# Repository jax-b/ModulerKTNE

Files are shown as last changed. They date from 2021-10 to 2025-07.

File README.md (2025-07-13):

# --------------

# Abandoned
Dam this needs a lot of work. What was i thinking on some of the decisions. Ill rework this into several separate repos in the future

# --------------

# ModulerKTNE
A real life keep talking and nobody explodes
The goal of this project it to make a modular [Keep Talking and Nobody Explodes game](https://keeptalkinggame.com/).
I also want this project to use the original game manual!
My eventual aim is to replicate every module.

# Discord
Join the [Discord](https://discord.gg/muyrytPZhW) to talk about the project  


Lets start out with my overall plan!
Each module should be self contained, meaning that that module knows weather or not it is solved.
Each module should be able to be configured from the central controller to replicate game scenarios.
The central controller should have a easy to use web interface.
Each module should look like it does in the game.
The game should know if it is being tampered with.

Coms between the central controller and the modules will likely use I2C with a master interrupt line.

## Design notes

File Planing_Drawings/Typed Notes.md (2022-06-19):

# Typed Notes
## ModAdders
### I2C Command List
 - 0x00 Get Module Type
 - 0x01 Get Module Config (Gets current scenario id and progress)
 - 0x02 Get Module Status (Should contain if solved)
 - 0x11 Set Module Solved Status (Sets if solved)
 - 0x12 Time Sync

### Time Keeping
~~- the current countdown time should be sent out to all modules using the 0xFF address~~
### I2C Address Locations
#### Modules
##### Front
| | | |
|:-:|:-:|:-:|
| Main | F1 | F2|
| F3 | F4 | F5 |
#### Back
| | | |
|:-:|:-:|:-:|
| B2 | B1 | Main |
| B5 | B4 | B3 |
#### Sides
| | | |
|:-:|:-:|:-:|
||50||
|53| Front Face | 51|
|| 52 ||
## SideCase
 - Each Side Should have its own PCB
 - Each Side Should have some indicators of each type (excluding serial and second factor)
 - Serial and Second Factor should be on the bottom
## FrontOfDevice
### Dimensions
 - The Device
  - 25" x 18" x 5"
 - The Modules
  - 8" x 8.365" (Depth has not been determined as of writing)
  - Locking Screw should be 1/4 20
  - PoGo pins should be centered at the top of the module
  - 6 PoGo pins are required
### Master Module
 - 7 segment display for time
 - warning indicator should just be two led's with diffuses and then a mask applied to the front of the diffuse to be stars
 - Inside of the device should be a extra sd card conatining stuff like WiFi Information (Parameters that cannot be set through the web interface)
## ModSlot
### Pin Order
| | | | | | |
|:-:|:-:|:-:|:-:|:-:|:-:|
|VCC|Ground|Addr|Interrupt|Clock|Data|
 - Interupt is active low
 - Addr is a voltage divider
 - Addr's voltage must be present at time of module boot in order to get address
 - Addr Should tie to the first analog input on the chip of the Module
## New Notes
- Any information that does not change throughout the course of a defusal session should be displayed on a eInk Display
- Information that does change should use either a LCD or OLED

## Gameplay port ID's
There are 6 types of ports in the game here is the id's we use to keep track of them
```
  1 = Port
  0 = not used
  1 = DVI
  1 = Parallel
  1 = PS/2
  1 = RJ45
  1 = Serial
  1 = SteroRCA
```

## RPI_Setup
#### go-rpio 
make sure that the following is set in boot/config.txt
```dtoverlay=gpio-no-irq```
#### no sudo access 
it is recommended that groups and permissions are assigned so that the software does not have to be run as root. Here is a example config for udev assuming that the groups are already created. While SPI is not necessary its here for the future if needed 
```
SUBSYSTEM=="spidev" , GROUP="spi" , MODE="0660"
KERNEL=="i2c-0"     , GROUP="i2c" , MODE="0660"
KERNEL=="i2c-[1-9]*", GROUP="i2c" , MODE="0660"
KERNEL=="gpiomem"   , GROUP="gpio", MODE="0660"
```

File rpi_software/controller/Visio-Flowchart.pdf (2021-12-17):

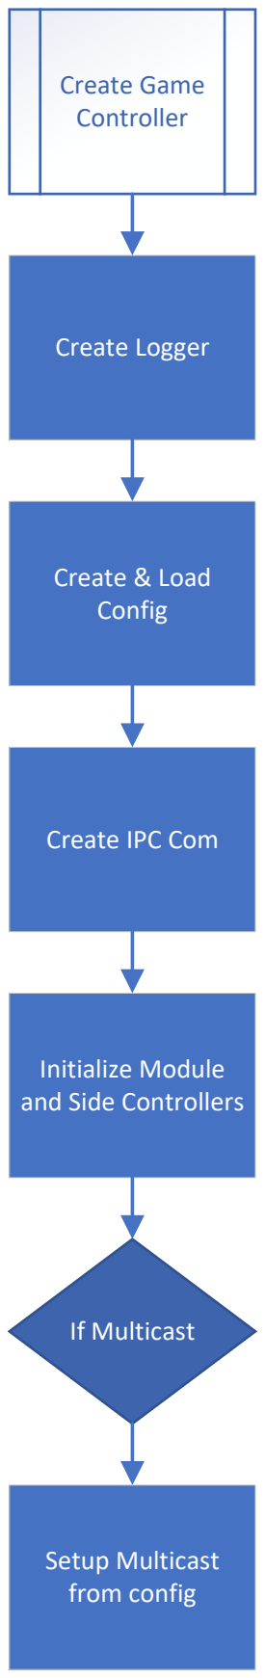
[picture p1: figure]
Create Game Controller; Create Logger; Create & Load Config; Create IPC Com; Initialize Module and Side Controllers; If Multicast; Setup Multicast from config
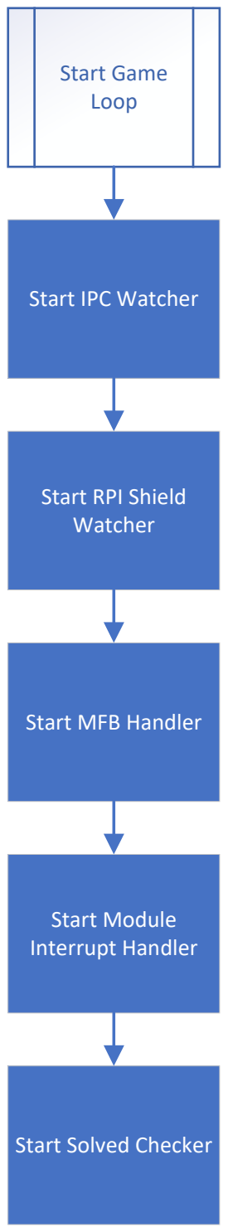
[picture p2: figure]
Start Game Loop; Start IPC Watcher; Start RPI Shield Watcher; Start Module Interrupt Handler; Start Solved Checker; Start MFB Handler

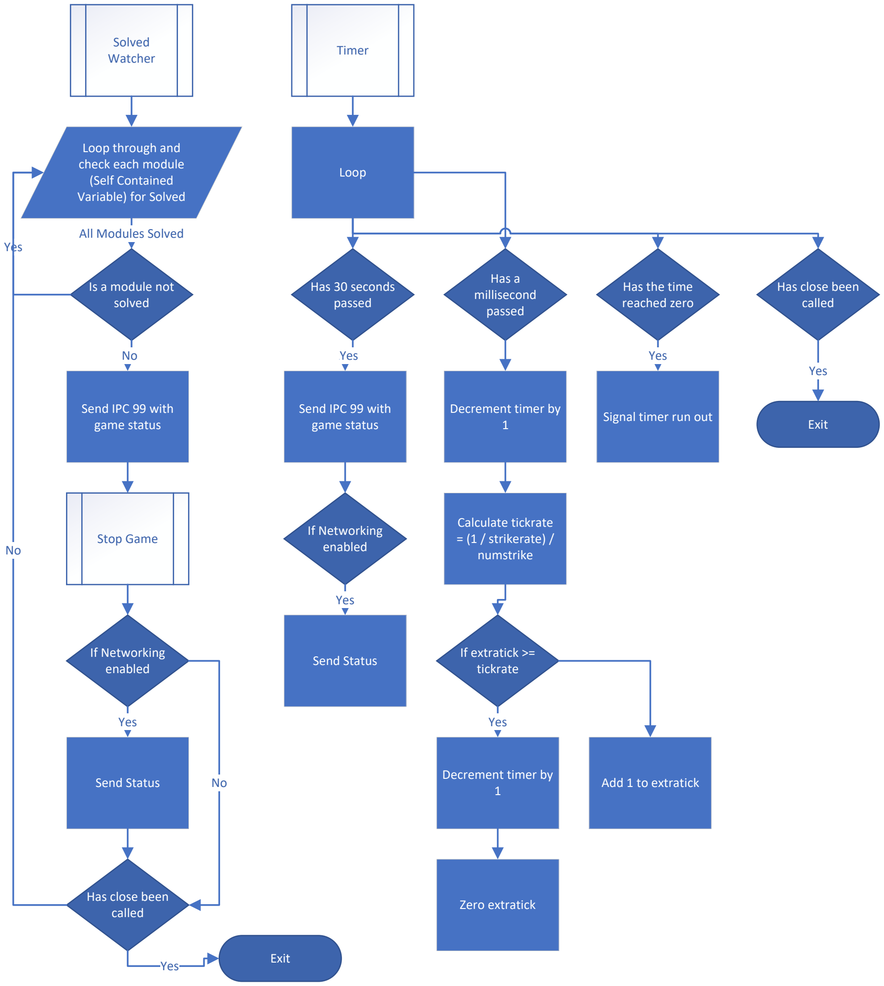
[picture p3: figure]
Solved Watcher; Is a module not solved; Yes; Loop through and check each module (Self Contained Variable) for Solved; All Modules Solved; Send IPC 99 with game status; Stop Game; If Networking enabled; Send Status; Timer; Has close been called; Has 30 seconds passed; Has a millisecond passed; Decrement timer by 1; Calculate tickrate = (1 / strikerate) / numstrike; If extratick >= tickrate; Zero extratick; Add 1 to extratick; Has the time reached zero; Signal timer run out; Exit; Exit Yes; Loop
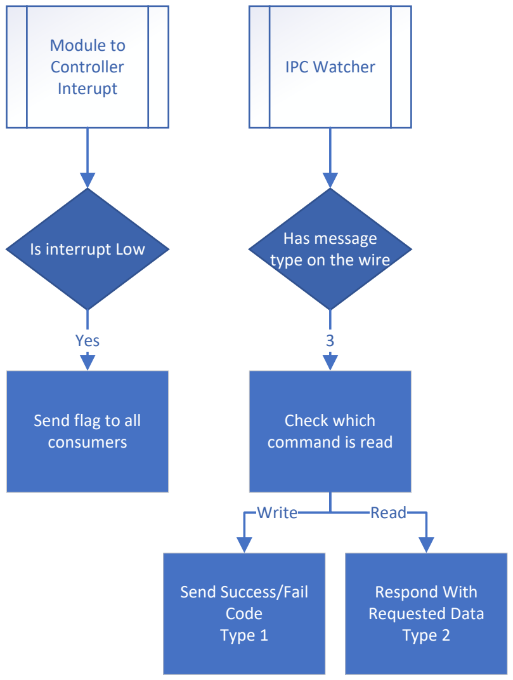
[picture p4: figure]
Module to Controller Interupt; IPC Watcher; Is interrupt Low; Send flag to all consumers; Yes; Has message type on the wire; Check which command is read; Send Success/Fail Code Type 1; Respond With Requested Data Type 2; Write; Read

Update IPC
Gamestatus

Send out current
status
Type 99

Every 10 seconds

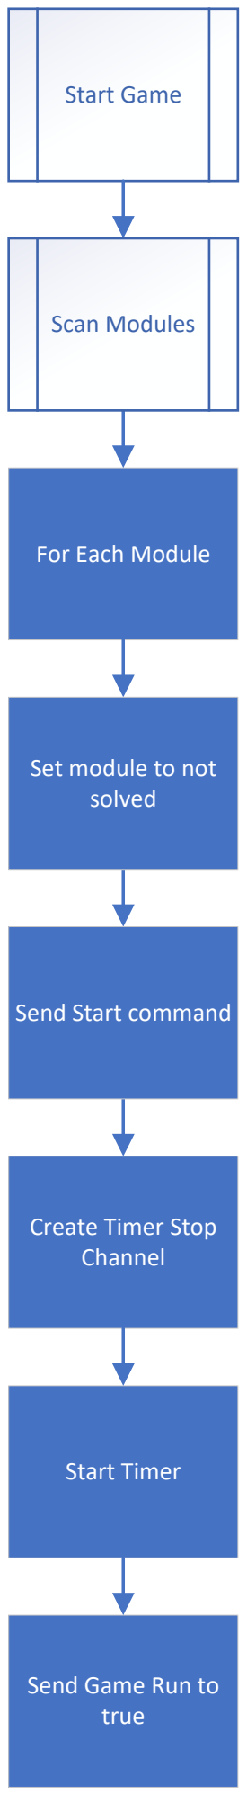
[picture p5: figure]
Start Game; For Each Module; Create Timer Stop Channel; Scan Modules; Set module to not solved; Send Start command; Start Timer; Send Game Run to true

Stop Game

Is the game
actually running

Stop Timer

Is module
present

Send Stop Game

For Each Module

Scan Modules

For Each Module

Test if module is
present

Send Full GameData
update

Yes

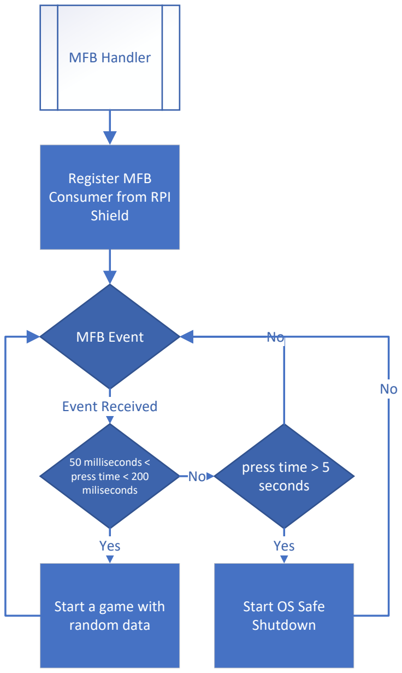
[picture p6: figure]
MFB Handler; Register MFB Consumer from RPI Shield; MFB Event; Event Received; 50 milliseconds < press time < 200 miliseconds; Start a game with random data; press time > 5 seconds; Yes; Start OS Safe Shutdown
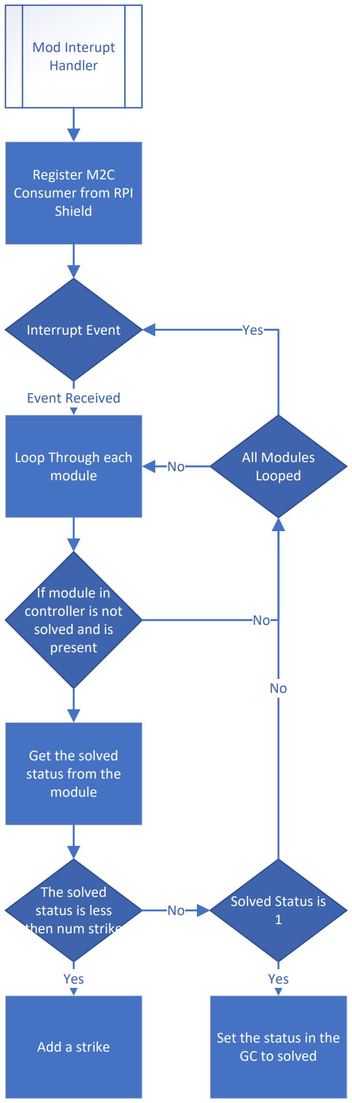
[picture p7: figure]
Mod Interupt Handler; Register M2C Consumer from RPI Shield; Interrupt Event; Loop Through each module; Event Received; If module in controller is not solved and is present; Get the solved status from the module; The solved status is less then num strike; Yes; Add a strike; Solved Status is 1 No; Set the status in the GC to solved; All Modules Looped No

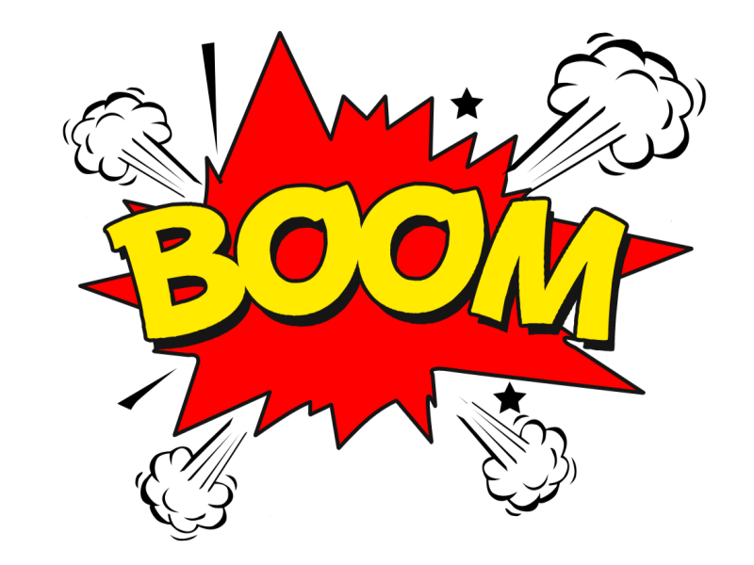
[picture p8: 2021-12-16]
rpi_software/netdisplay/cmd/webcode/images/boom.png

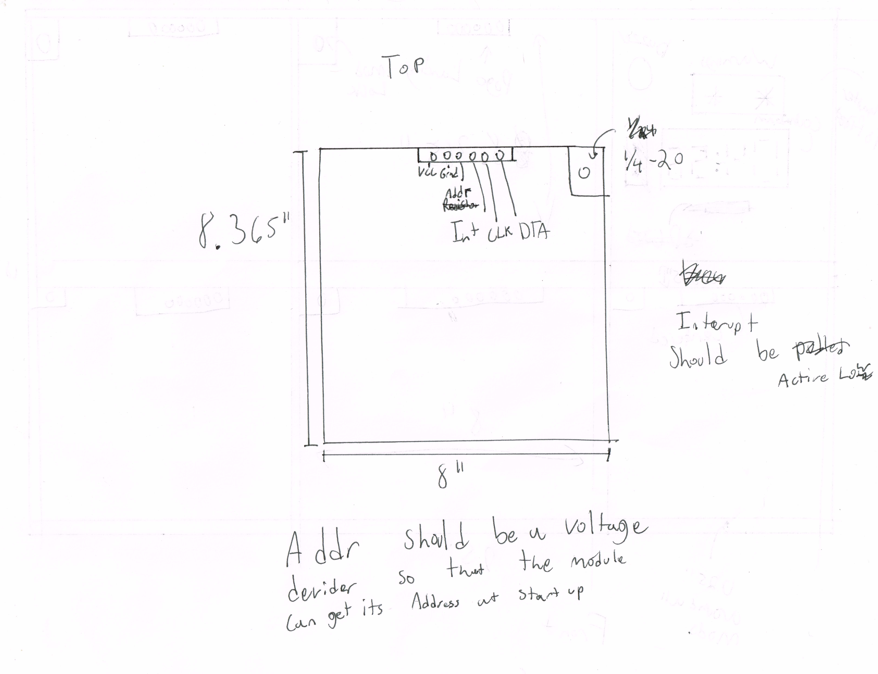
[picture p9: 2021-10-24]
Planing_Drawings/ModSlot.JPG

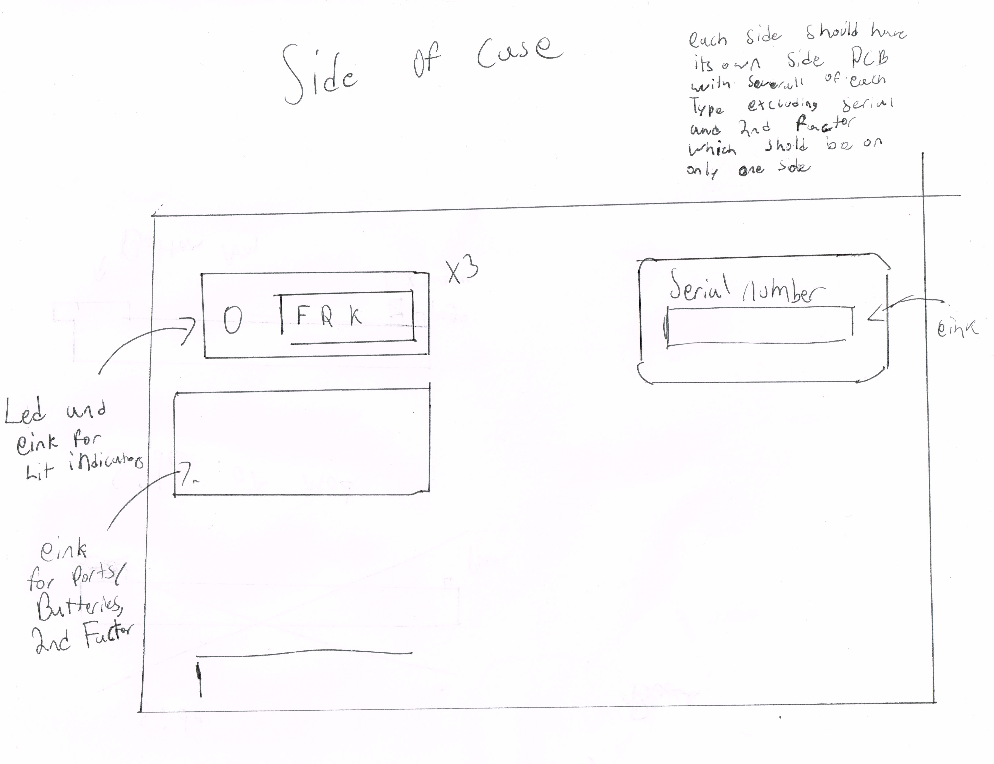
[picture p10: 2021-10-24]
Planing_Drawings/SideCase.JPG

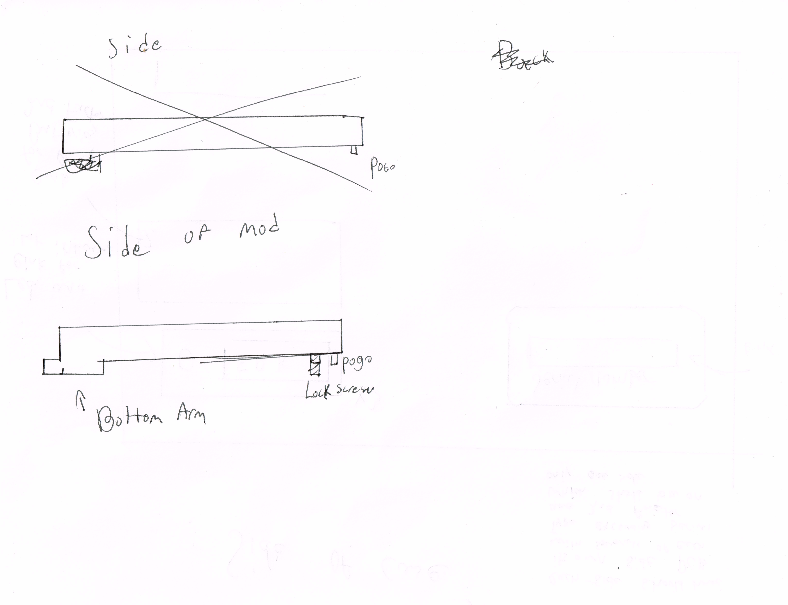
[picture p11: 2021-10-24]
Planing_Drawings/SideOfMod.JPG

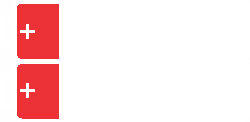
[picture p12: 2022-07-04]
SidePanel/Artwork/AA - RED.jpg

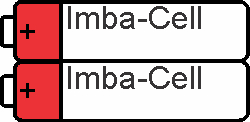
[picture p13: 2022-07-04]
SidePanel/Artwork/AA.jpg

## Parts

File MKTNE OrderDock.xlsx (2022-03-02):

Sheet: Totals
Manufacturer Part Number | Manufacturer Name | Description | Digi-Key Part Number 1 | Requested Quantity 1
ABLS-12.000MHZ-B4-T | Abracon LLC | CRYSTAL 12.0000MHZ 18PF SMD | 535-10218-1-ND | 9
A-CSL-S-020-B7-A | Assmann WSW Components | CONN PIN SPRING LOAD 5.207MM AU | AE11599-ND | 54
ADC144EUQ-13 | Diodes Incorporated | IC TRANSISTOR SOT363 | ADC144EUQ-13DICT-ND | 8
C0805Z5U500-103MNE-CT | Venkel | CAP CER 0.01UF 50V Z5U 0805 | 2679-C0805Z5U500-103MNE-CT-ND | 2
CL21A106KOQNNNE | Samsung Electro-Mechanics | CAP CER 10UF 16V X5R 0805 | 1276-1096-1-ND | 5
CL21B103KBANNNC | Samsung Electro-Mechanics | CAP CER 10000PF 50V X7R 0805 | 1276-1015-1-ND | 3
CL21B104KACNNNC | Samsung Electro-Mechanics | CAP CER 0.1UF 25V X7R 0805 | 1276-1099-1-ND | 92
CL21B105KAFNNNE | Samsung Electro-Mechanics | CAP CER 1UF 25V X7R 0805 | 1276-1066-1-ND | 15
CL21C270JCANNNC | Samsung Electro-Mechanics | CAP CER 27PF 100V C0G/NP0 0805 | 1276-2622-1-ND | 18
CL31B106KQHNFNE | Samsung Electro-Mechanics | CAP CER 10UF 6.3V X7R 1206 | 1276-3107-1-ND | 15
CMS0231KLX | CUI Devices | SPEAKER 8OHM 2W ENCLOSED 82DB | 102-1300-ND | 5
CPF0603B10KE1 | TE Connectivity Passive Product | RES SMD 10K OHM 0.1% 1/16W 0603 | A102331CT-ND | 12
CRGP0603F27R | TE Connectivity Passive Product | RES 27 OHM 1% 1/4W 0603 | A130397CT-ND | 18
CRM0805-FX-51R0ELF | Bourns Inc. | RES SMD 51 OHM 1% 1/4W 0805 | CRM0805-FX-51R0ELFCT-ND | 6
ERA-3AEB512V | Panasonic Electronic Components | RES SMD 5.1K OHM 0.1% 1/10W 0603 | P5.1KDBCT-ND | 18
ESR03EZPF1001 | Rohm Semiconductor | RES SMD 1K OHM 1% 1/4W 0603 | RHM1.00KADCT-ND | 18
JMK316BBJ107MLHT | Taiyo Yuden | CAP CER 100UF 6.3V X5R 1206 | 587-3716-1-ND | 12
MAX7221CWG+T | Analog Devices Inc./Maxim Integrated | IC DRVR 7 SEGMNT 8 DIGIT 24SOIC | MAX7221CWG+CT-ND | 2
NCP1117DTARKG | onsemi | IC REG LINEAR POS ADJ 1A DPAK | NCP1117DTARKGOSCT-ND | 9
RG1608P-562-B-T5 | Susumu | RES SMD 5.6K OHM 0.1% 1/10W 0603 | RG16P5.6KBCT-ND | 9
RK73H2ATTD1100F | KOA Speer Electronics, Inc. | RES 110 OHM 1% 1/4W 0805 | 2019-RK73H2ATTD1100FCT-ND | 12
RK73H2ATTD2700F | KOA Speer Electronics, Inc. | RES 270 OHM 1% 1/4W 0805 | 2019-RK73H2ATTD2700FCT-ND | 5
RK73H2ATTD30R0F | KOA Speer Electronics, Inc. | RES 30 OHM 1% 1/4W 0805 | 2019-RK73H2ATTD30R0FCT-ND | 14
RK73H2ATTD91R0F | KOA Speer Electronics, Inc. | RES 91 OHM 1% 1/4W 0805 | 2019-RK73H2ATTD91R0FCT-ND | 30
RNCP0805FTD150R | Stackpole Electronics Inc | RES 150 OHM 1% 1/4W 0805 | RNCP0805FTD150RCT-ND | 14
RNCP0805FTD4K99 | Stackpole Electronics Inc | RES 4.99K OHM 1% 1/4W 0805 | RNCP0805FTD4K99CT-ND | 2
S02B-XASS-1(LF)(SN) | JST Sales America Inc. | CONN HEADER R/A 2POS 2.5MM | 455-2044-ND | 2
S04B-XASK-1(LF)(SN) | JST Sales America Inc. | CONN HEADER R/A 4POS 2.5MM | 455-4090-ND | 6
S05B-XASK-1(LF)(SN) | JST Sales America Inc. | CONN HEADER R/A 5POS 2.5MM | 455-4135-ND | 30
SC0914(7) | Raspberry Pi | RP2040TR7 | 2648-SC0914(7)CT-ND | 9
SG73S2ATTD4701F | KOA Speer Electronics, Inc. | RES 4.7K OHM 1% 1/4W 0805 | 2019-SG73S2ATTD4701FCT-ND | 2
SSM2305RMZ-R2 | Analog Devices Inc. | IC AMP CLASS D MONO 2.8W 8MSOP | SSM2305RMZ-R2CT-ND | 5
W25Q128JVSIQ | Winbond Electronics | IC FLASH 128MBIT SPI/QUAD 8SOIC | W25Q128JVSIQ-ND | 9
XZDGK54W-8 | SunLED | LED GREEN CLEAR CHIP SMD | 1497-1435-1-ND | 12
XZFBB54W-8 | SunLED | LED BLUE CLEAR CHIP SMD | 1497-1437-1-ND | 12
XZMDK54W-8 | SunLED | LED RED CLEAR CHIP SMD | 1497-1431-1-ND | 28
XZMYK54W-8 | SunLED | LED YELLOW CLEAR CHIP SMD | 1497-1432-1-ND | 12

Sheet: EveryPart
Manufacturer Part Number | Manufacturer Name | Description | Digi-Key Part Number 1 | Unit Price 1 | Extended Price 1 | TotalMultipled | SRC
S05B-XASK-1(LF)(SN) | JST Sales America Inc. | CONN HEADER R/A 5POS 2.5MM | 455-4135-ND | 0.56000 | $1.12 | 22 | MKTNE_MODCON
S04B-XASK-1(LF)(SN) | JST Sales America Inc. | CONN HEADER R/A 4POS 2.5MM | 455-4090-ND | 0.53000 | $0.53 | 2 | MKTNE_POWERCON
S05B-XASK-1(LF)(SN) | JST Sales America Inc. | CONN HEADER R/A 5POS 2.5MM | 455-4135-ND | 0.56000 | $2.24 | 8 | MKTNE_RPICTRL
S04B-XASK-1(LF)(SN) | JST Sales America Inc. | CONN HEADER R/A 4POS 2.5MM | 455-4090-ND | 0.53000 | $1.06 | 4 | MKTNE_RPICTRL
ADC144EUQ-13 | Diodes Incorporated | IC TRANSISTOR SOT363 | ADC144EUQ-13DICT-ND | 0.39000 | $0.39 | 2 | MKTNE_RPICTRL
SSM2305RMZ-R2 | Analog Devices Inc. | IC AMP CLASS D MONO 2.8W 8MSOP | SSM2305RMZ-R2CT-ND | 2.53000 | $2.53 | 2 | MKTNE_RPICTRL
CMS0231KLX | CUI Devices | SPEAKER 8OHM 2W ENCLOSED 82DB | 102-1300-ND | 6.63000 | $6.63 | 2 | MKTNE_RPICTRL
CL21B104KACNNNC | Samsung Electro-Mechanics | CAP CER 0.1UF 25V X7R 0805 | 1276-1099-1-ND | 0.10000 | $0.10 | 2 | MKTNE_RPICTRL
CL21A106KOQNNNE | Samsung Electro-Mechanics | CAP CER 10UF 16V X5R 0805 | 1276-1096-1-ND | 0.11000 | $0.11 | 2 | MKTNE_RPICTRL
RK73H2ATTD2700F | KOA Speer Electronics, Inc. | RES 270 OHM 1% 1/4W 0805 | 2019-RK73H2ATTD2700FCT-ND | 0.10000 | $0.10 | 2 | MKTNE_RPICTRL
RNCP0805FTD150R | Stackpole Electronics Inc | RES 150 OHM 1% 1/4W 0805 | RNCP0805FTD150RCT-ND | 0.10000 | $0.10 | 2 | MKTNE_RPICTRL
RK73H2ATTD30R0F | KOA Speer Electronics, Inc. | RES 30 OHM 1% 1/4W 0805 | 2019-RK73H2ATTD30R0FCT-ND | 0.10000 | $0.40 | 8 | MKTNE_RPICTRL
MAX7221CWG+T | Analog Devices Inc./Maxim Integrated | IC DRVR 7 SEGMNT 8 DIGIT 24SOIC | MAX7221CWG+CT-ND | 10.77000 | $10.77 | 2 | MKTNE_RPICTRL
XZMDK54W-8 | SunLED | LED RED CLEAR CHIP SMD | 1497-1431-1-ND | 0.46000 | $3.68 | 16 | MKTNE_RPICTRL
RNCP0805FTD4K99 | Stackpole Electronics Inc | RES 4.99K OHM 1% 1/4W 0805 | RNCP0805FTD4K99CT-ND | 0.10000 | $0.10 | 2 | MKTNE_RPICTRL
SG73S2ATTD4701F | KOA Speer Electronics, Inc. | RES 4.7K OHM 1% 1/4W 0805 | 2019-SG73S2ATTD4701FCT-ND | 0.19000 | $0.19 | 2 | MKTNE_RPICTRL
S02B-XASS-1(LF)(SN) | JST Sales America Inc. | CONN HEADER R/A 2POS 2.5MM | 455-2044-ND | 0.45000 | $0.45 | 2 | MKTNE_RPICTRL
C0805Z5U500-103MNE-CT | Venkel | CAP CER 0.01UF 50V Z5U 0805 | 2679-C0805Z5U500-103MNE-CT-ND | 0.02800 | $0.14 | 2 | MKTNE_RPICTRL
XZFBB54W-8 | SunLED | LED BLUE CLEAR CHIP SMD | 1497-1437-1-ND | 0.57000 | $2.28 | 12 | OTS_Simon
XZMYK54W-8 | SunLED | LED YELLOW CLEAR CHIP SMD | 1497-1432-1-ND | 0.46000 | $1.84 | 12 | OTS_Simon
XZDGK54W-8 | SunLED | LED GREEN CLEAR CHIP SMD | 1497-1435-1-ND | 0.67000 | $2.68 | 12 | OTS_Simon
XZMDK54W-8 | SunLED | LED RED CLEAR CHIP SMD | 1497-1431-1-ND | 0.46000 | $1.84 | 12 | OTS_Simon
W25Q128JVSIQ | Winbond Electronics | IC FLASH 128MBIT SPI/QUAD 8SOIC | W25Q128JVSIQ-ND | 1.88000 | $1.88 | 3 | OTS_Simon
NCP1117DTARKG | onsemi | IC REG LINEAR POS ADJ 1A DPAK | NCP1117DTARKGOSCT-ND | 0.63000 | $0.63 | 3 | OTS_Simon
SC0914(7) | Raspberry Pi | RP2040TR7 | 2648-SC0914(7)CT-ND | 1.00000 | $1.00 | 3 | OTS_Simon
ABLS-12.000MHZ-B4-T | Abracon LLC | CRYSTAL 12.0000MHZ 18PF SMD | 535-10218-1-ND | 0.32000 | $0.32 | 3 | OTS_Simon
SSM2305RMZ-R2 | Analog Devices Inc. | IC AMP CLASS D MONO 2.8W 8MSOP | SSM2305RMZ-R2CT-ND | 2.53000 | $2.53 | 3 | OTS_Simon
ADC144EUQ-13 | Diodes Incorporated | IC TRANSISTOR SOT363 | ADC144EUQ-13DICT-ND | 0.39000 | $0.78 | 6 | OTS_Simon
CMS0231KLX | CUI Devices | SPEAKER 8OHM 2W ENCLOSED 82DB | 102-1300-ND | 6.63000 | $6.63 | 3 | OTS_Simon
A-CSL-S-020-B7-A | Assmann WSW Components | CONN PIN SPRING LOAD 5.207MM AU | AE11599-ND | 0.78000 | $4.68 | 18 | OTS_Simon
CL31B106KQHNFNE | Samsung Electro-Mechanics | CAP CER 10UF 6.3V X7R 1206 | 1276-3107-1-ND | 0.18000 | $0.18 | 3 | OTS_Simon
CRGP0603F27R | TE Connectivity Passive Product | RES 27 OHM 1% 1/4W 0603 | A130397CT-ND | 0.18000 | $0.36 | 6 | OTS_Simon
RNCP0805FTD150R | Stackpole Electronics Inc | RES 150 OHM 1% 1/4W 0805 | RNCP0805FTD150RCT-ND | 0.10000 | $0.20 | 6 | OTS_Simon
RK73H2ATTD91R0F | KOA Speer Electronics, Inc. | RES 91 OHM 1% 1/4W 0805 | 2019-RK73H2ATTD91R0FCT-ND | 0.10000 | $0.60 | 18 | OTS_Simon
CL21C270JCANNNC | Samsung Electro-Mechanics | CAP CER 27PF 100V C0G/NP0 0805 | 1276-2622-1-ND | 0.10000 | $0.20 | 6 | OTS_Simon
CL21A106KOQNNNE | Samsung Electro-Mechanics | CAP CER 10UF 16V X5R 0805 | 1276-1096-1-ND | 0.11000 | $0.11 | 3 | OTS_Simon
CL21B103KBANNNC | Samsung Electro-Mechanics | CAP CER 10000PF 50V X7R 0805 | 1276-1015-1-ND | 0.10000 | $0.10 | 3 | OTS_Simon
CL21B104KACNNNC | Samsung Electro-Mechanics | CAP CER 0.1UF 25V X7R 0805 | 1276-1099-1-ND | 0.04000 | $0.40 | 30 | OTS_Simon
RG1608P-562-B-T5 | Susumu | RES SMD 5.6K OHM 0.1% 1/10W 0603 | RG16P5.6KBCT-ND | 0.50000 | $0.50 | 3 | OTS_Simon
ERA-3AEB512V | Panasonic Electronic Components | RES SMD 5.1K OHM 0.1% 1/10W 0603 | P5.1KDBCT-ND | 0.35000 | $0.70 | 6 | OTS_Simon
CPF0603B10KE1 | TE Connectivity Passive Product | RES SMD 10K OHM 0.1% 1/16W 0603 | A102331CT-ND | 0.67000 | $0.67 | 3 | OTS_Simon
ESR03EZPF1001 | Rohm Semiconductor | RES SMD 1K OHM 1% 1/4W 0603 | RHM1.00KADCT-ND | 0.15000 | $0.30 | 6 | OTS_Simon
CRM0805-FX-51R0ELF | Bourns Inc. | RES SMD 51 OHM 1% 1/4W 0805 | CRM0805-FX-51R0ELFCT-ND | 0.10000 | $0.20 | 6 | OTS_Simon
RK73H2ATTD30R0F | KOA Speer Electronics, Inc. | RES 30 OHM 1% 1/4W 0805 | 2019-RK73H2ATTD30R0FCT-ND | 0.10000 | $0.20 | 6 | OTS_Simon
RK73H2ATTD1100F | KOA Speer Electronics, Inc. | RES 110 OHM 1% 1/4W 0805 | 2019-RK73H2ATTD1100FCT-ND | 0.10000 | $0.40 | 12 | OTS_Simon
RK73H2ATTD2700F | KOA Speer Electronics, Inc. | RES 270 OHM 1% 1/4W 0805 | 2019-RK73H2ATTD2700FCT-ND | 0.10000 | $0.10 | 3 | OTS_Simon
CL21B105KAFNNNE | Samsung Electro-Mechanics | CAP CER 1UF 25V X7R 0805 | 1276-1066-1-ND | 0.10000 | $0.20 | 6 | OTS_Simon
W25Q128JVSIQ | Winbond Electronics | IC FLASH 128MBIT SPI/QUAD 8SOIC | W25Q128JVSIQ-ND | 1.88000 | $1.88 | 3 | OTS_Button
NCP1117DTARKG | onsemi | IC REG LINEAR POS ADJ 1A DPAK | NCP1117DTARKGOSCT-ND | 0.63000 | $0.63 | 3 | OTS_Button
SC0914(7) | Raspberry Pi | RP2040TR7 | 2648-SC0914(7)CT-ND | 1.00000 | $1.00 | 3 | OTS_Button
ABLS-12.000MHZ-B4-T | Abracon LLC | CRYSTAL 12.0000MHZ 18PF SMD | 535-10218-1-ND | 0.32000 | $0.32 | 3 | OTS_Button
A-CSL-S-020-B7-A | Assmann WSW Components | CONN PIN SPRING LOAD 5.207MM AU | AE11599-ND | 0.78000 | $4.68 | 18 | OTS_Button
RNCP0805FTD150R | Stackpole Electronics Inc | RES 150 OHM 1% 1/4W 0805 | RNCP0805FTD150RCT-ND | 0.10000 | $0.10 | 3 | OTS_Button
RK73H2ATTD91R0F | KOA Speer Electronics, Inc. | RES 91 OHM 1% 1/4W 0805 | 2019-RK73H2ATTD91R0FCT-ND | 0.10000 | $0.20 | 6 | OTS_Button
CRGP0603F27R | TE Connectivity Passive Product | RES 27 OHM 1% 1/4W 0603 | A130397CT-ND | 0.18000 | $0.36 | 6 | OTS_Button
ERA-3AEB512V | Panasonic Electronic Components | RES SMD 5.1K OHM 0.1% 1/10W 0603 | P5.1KDBCT-ND | 0.35000 | $0.70 | 6 | OTS_Button
CPF0603B10KE1 | TE Connectivity Passive Product | RES SMD 10K OHM 0.1% 1/16W 0603 | A102331CT-ND | 0.67000 | $1.34 | 6 | OTS_Button
CL21B104KACNNNC | Samsung Electro-Mechanics | CAP CER 0.1UF 25V X7R 0805 | 1276-1099-1-ND | 0.04000 | $0.40 | 30 | OTS_Button
CL21B105KAFNNNE | Samsung Electro-Mechanics | CAP CER 1UF 25V X7R 0805 | 1276-1066-1-ND | 0.10000 | $0.10 | 3 | OTS_Button
RG1608P-562-B-T5 | Susumu | RES SMD 5.6K OHM 0.1% 1/10W 0603 | RG16P5.6KBCT-ND | 0.50000 | $0.50 | 3 | OTS_Button
ESR03EZPF1001 | Rohm Semiconductor | RES SMD 1K OHM 1% 1/4W 0603 | RHM1.00KADCT-ND | 0.15000 | $0.30 | 6 | OTS_Button
CL21C270JCANNNC | Samsung Electro-Mechanics | CAP CER 27PF 100V C0G/NP0 0805 | 1276-2622-1-ND | 0.10000 | $0.20 | 6 | OTS_Button
CL31B106KQHNFNE | Samsung Electro-Mechanics | CAP CER 10UF 6.3V X7R 1206 | 1276-3107-1-ND | 0.18000 | $0.36 | 6 | OTS_Button
JMK316BBJ107MLHT | Taiyo Yuden | CAP CER 100UF 6.3V X5R 1206 | 587-3716-1-ND | 0.72000 | $1.44 | 6 | OTS_Button
JMK316BBJ107MLHT | Taiyo Yuden | CAP CER 100UF 6.3V X5R 1206 | 587-3716-1-ND | 0.72000 | $1.44 | 6 | OTS_Wires
CL31B106KQHNFNE | Samsung Electro-Mechanics | CAP CER 10UF 6.3V X7R 1206 | 1276-3107-1-ND | 0.18000 | $0.36 | 6 | OTS_Wires
CL21B104KACNNNC | Samsung Electro-Mechanics | CAP CER 0.1UF 25V X7R 0805 | 1276-1099-1-ND | 0.04000 | $0.40 | 30 | OTS_Wires
CL21B105KAFNNNE | Samsung Electro-Mechanics | CAP CER 1UF 25V X7R 0805 | 1276-1066-1-ND | 0.10000 | $0.20 | 6 | OTS_Wires
CL21C270JCANNNC | Samsung Electro-Mechanics | CAP CER 27PF 100V C0G/NP0 0805 | 1276-2622-1-ND | 0.10000 | $0.20 | 6 | OTS_Wires
A-CSL-S-020-B7-A | Assmann WSW Components | CONN PIN SPRING LOAD 5.207MM AU | AE11599-ND | 0.78000 | $4.68 | 18 | OTS_Wires
RG1608P-562-B-T5 | Susumu | RES SMD 5.6K OHM 0.1% 1/10W 0603 | RG16P5.6KBCT-ND | 0.50000 | $0.50 | 3 | OTS_Wires
CPF0603B10KE1 | TE Connectivity Passive Product | RES SMD 10K OHM 0.1% 1/16W 0603 | A102331CT-ND | 0.67000 | $0.67 | 3 | OTS_Wires
ERA-3AEB512V | Panasonic Electronic Components | RES SMD 5.1K OHM 0.1% 1/10W 0603 | P5.1KDBCT-ND | 0.35000 | $0.70 | 6 | OTS_Wires
ESR03EZPF1001 | Rohm Semiconductor | RES SMD 1K OHM 1% 1/4W 0603 | RHM1.00KADCT-ND | 0.15000 | $0.30 | 6 | OTS_Wires
CRGP0603F27R | TE Connectivity Passive Product | RES 27 OHM 1% 1/4W 0603 | A130397CT-ND | 0.18000 | $0.36 | 6 | OTS_Wires
RK73H2ATTD91R0F | KOA Speer Electronics, Inc. | RES 91 OHM 1% 1/4W 0805 | 2019-RK73H2ATTD91R0FCT-ND | 0.10000 | $0.20 | 6 | OTS_Wires
RNCP0805FTD150R | Stackpole Electronics Inc | RES 150 OHM 1% 1/4W 0805 | RNCP0805FTD150RCT-ND | 0.10000 | $0.10 | 3 | OTS_Wires
NCP1117DTARKG | onsemi | IC REG LINEAR POS ADJ 1A DPAK | NCP1117DTARKGOSCT-ND | 0.63000 | $0.63 | 3 | OTS_Wires
W25Q128JVSIQ | Winbond Electronics | IC FLASH 128MBIT SPI/QUAD 8SOIC | W25Q128JVSIQ-ND | 1.88000 | $1.88 | 3 | OTS_Wires
SC0914(7) | Raspberry Pi | RP2040TR7 | 2648-SC0914(7)CT-ND | 1.00000 | $1.00 | 3 | OTS_Wires
ABLS-12.000MHZ-B4-T | Abracon LLC | CRYSTAL 12.0000MHZ 18PF SMD | 535-10218-1-ND | 0.32000 | $0.32 | 3 | OTS_Wires

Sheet: MKTNE_MODCON
Manufacturer Part Number | Manufacturer Name | Description | Requested Quantity 1 | Digi-Key Part Number 1 | Unit Price 1 | Extended Price 1 | TotalQTY | Multiplier
S05B-XASK-1(LF)(SN) | JST Sales America Inc. | CONN HEADER R/A 5POS 2.5MM | 2 | 455-4135-ND | 0.56000 | $1.12 | 22 | 11

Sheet: MKTNE_POWERCON
Manufacturer Part Number | Manufacturer Name | Description | Requested Quantity 1 | Digi-Key Part Number 1 | Unit Price 1 | Extended Price 1 | TotalQTY | Multiplier
S04B-XASK-1(LF)(SN) | JST Sales America Inc. | CONN HEADER R/A 4POS 2.5MM | 1 | 455-4090-ND | 0.53000 | $0.53 | 2 | 2

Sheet: MKTNE_RPICTRL
Manufacturer Part Number | Manufacturer Name | Description | Requested Quantity 1 | Digi-Key Part Number 1 | Unit Price 1 | Extended Price 1 | TotalQTY | Multiplier
S05B-XASK-1(LF)(SN) | JST Sales America Inc. | CONN HEADER R/A 5POS 2.5MM | 4 | 455-4135-ND | 0.56000 | $2.24 | 8 | 2
S04B-XASK-1(LF)(SN) | JST Sales America Inc. | CONN HEADER R/A 4POS 2.5MM | 2 | 455-4090-ND | 0.53000 | $1.06 | 4
ADC144EUQ-13 | Diodes Incorporated | IC TRANSISTOR SOT363 | 1 | ADC144EUQ-13DICT-ND | 0.39000 | $0.39 | 2
SSM2305RMZ-R2 | Analog Devices Inc. | IC AMP CLASS D MONO 2.8W 8MSOP | 1 | SSM2305RMZ-R2CT-ND | 2.53000 | $2.53 | 2
CMS0231KLX | CUI Devices | SPEAKER 8OHM 2W ENCLOSED 82DB | 1 | 102-1300-ND | 6.63000 | $6.63 | 2
CL21B104KACNNNC | Samsung Electro-Mechanics | CAP CER 0.1UF 25V X7R 0805 | 1 | 1276-1099-1-ND | 0.10000 | $0.10 | 2
CL21A106KOQNNNE | Samsung Electro-Mechanics | CAP CER 10UF 16V X5R 0805 | 1 | 1276-1096-1-ND | 0.11000 | $0.11 | 2
RK73H2ATTD2700F | KOA Speer Electronics, Inc. | RES 270 OHM 1% 1/4W 0805 | 1 | 2019-RK73H2ATTD2700FCT-ND | 0.10000 | $0.10 | 2
RNCP0805FTD150R | Stackpole Electronics Inc | RES 150 OHM 1% 1/4W 0805 | 1 | RNCP0805FTD150RCT-ND | 0.10000 | $0.10 | 2
RK73H2ATTD30R0F | KOA Speer Electronics, Inc. | RES 30 OHM 1% 1/4W 0805 | 4 | 2019-RK73H2ATTD30R0FCT-ND | 0.10000 | $0.40 | 8
MAX7221CWG+T | Analog Devices Inc./Maxim Integrated | IC DRVR 7 SEGMNT 8 DIGIT 24SOIC | 1 | MAX7221CWG+CT-ND | 10.77000 | $10.77 | 2
XZMDK54W-8 | SunLED | LED RED CLEAR CHIP SMD | 8 | 1497-1431-1-ND | 0.46000 | $3.68 | 16
RNCP0805FTD4K99 | Stackpole Electronics Inc | RES 4.99K OHM 1% 1/4W 0805 | 1 | RNCP0805FTD4K99CT-ND | 0.10000 | $0.10 | 2
SG73S2ATTD4701F | KOA Speer Electronics, Inc. | RES 4.7K OHM 1% 1/4W 0805 | 1 | 2019-SG73S2ATTD4701FCT-ND | 0.19000 | $0.19 | 2
S02B-XASS-1(LF)(SN) | JST Sales America Inc. | CONN HEADER R/A 2POS 2.5MM | 1 | 455-2044-ND | 0.45000 | $0.45 | 2
C0805Z5U500-103MNE-CT | Venkel | CAP CER 0.01UF 50V Z5U 0805 | 1 | 2679-C0805Z5U500-103MNE-CT-ND | 0.02800 | $0.14 | 2

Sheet: OTS_Simon
Manufacturer Part Number | Manufacturer Name | Description | Requested Quantity 1 | Digi-Key Part Number 1 | Unit Price 1 | Extended Price 1 | TotalQTY | Multiplier
XZFBB54W-8 | SunLED | LED BLUE CLEAR CHIP SMD | 4 | 1497-1437-1-ND | 0.57000 | $2.28 | 12 | 3
XZMYK54W-8 | SunLED | LED YELLOW CLEAR CHIP SMD | 4 | 1497-1432-1-ND | 0.46000 | $1.84 | 12
XZDGK54W-8 | SunLED | LED GREEN CLEAR CHIP SMD | 4 | 1497-1435-1-ND | 0.67000 | $2.68 | 12
XZMDK54W-8 | SunLED | LED RED CLEAR CHIP SMD | 4 | 1497-1431-1-ND | 0.46000 | $1.84 | 12
W25Q128JVSIQ | Winbond Electronics | IC FLASH 128MBIT SPI/QUAD 8SOIC | 1 | W25Q128JVSIQ-ND | 1.88000 | $1.88 | 3
NCP1117DTARKG | onsemi | IC REG LINEAR POS ADJ 1A DPAK | 1 | NCP1117DTARKGOSCT-ND | 0.63000 | $0.63 | 3
SC0914(7) | Raspberry Pi | RP2040TR7 | 1 | 2648-SC0914(7)CT-ND | 1.00000 | $1.00 | 3
ABLS-12.000MHZ-B4-T | Abracon LLC | CRYSTAL 12.0000MHZ 18PF SMD | 1 | 535-10218-1-ND | 0.32000 | $0.32 | 3
SSM2305RMZ-R2 | Analog Devices Inc. | IC AMP CLASS D MONO 2.8W 8MSOP | 1 | SSM2305RMZ-R2CT-ND | 2.53000 | $2.53 | 3
ADC144EUQ-13 | Diodes Incorporated | IC TRANSISTOR SOT363 | 2 | ADC144EUQ-13DICT-ND | 0.39000 | $0.78 | 6
CMS0231KLX | CUI Devices | SPEAKER 8OHM 2W ENCLOSED 82DB | 1 | 102-1300-ND | 6.63000 | $6.63 | 3
A-CSL-S-020-B7-A | Assmann WSW Components | CONN PIN SPRING LOAD 5.207MM AU | 6 | AE11599-ND | 0.78000 | $4.68 | 18
CL31B106KQHNFNE | Samsung Electro-Mechanics | CAP CER 10UF 6.3V X7R 1206 | 1 | 1276-3107-1-ND | 0.18000 | $0.18 | 3
CRGP0603F27R | TE Connectivity Passive Product | RES 27 OHM 1% 1/4W 0603 | 2 | A130397CT-ND | 0.18000 | $0.36 | 6
RNCP0805FTD150R | Stackpole Electronics Inc | RES 150 OHM 1% 1/4W 0805 | 2 | RNCP0805FTD150RCT-ND | 0.10000 | $0.20 | 6
RK73H2ATTD91R0F | KOA Speer Electronics, Inc. | RES 91 OHM 1% 1/4W 0805 | 6 | 2019-RK73H2ATTD91R0FCT-ND | 0.10000 | $0.60 | 18
CL21C270JCANNNC | Samsung Electro-Mechanics | CAP CER 27PF 100V C0G/NP0 0805 | 2 | 1276-2622-1-ND | 0.10000 | $0.20 | 6
CL21A106KOQNNNE | Samsung Electro-Mechanics | CAP CER 10UF 16V X5R 0805 | 1 | 1276-1096-1-ND | 0.11000 | $0.11 | 3
CL21B103KBANNNC | Samsung Electro-Mechanics | CAP CER 10000PF 50V X7R 0805 | 1 | 1276-1015-1-ND | 0.10000 | $0.10 | 3
CL21B104KACNNNC | Samsung Electro-Mechanics | CAP CER 0.1UF 25V X7R 0805 | 10 | 1276-1099-1-ND | 0.04000 | $0.40 | 30
RG1608P-562-B-T5 | Susumu | RES SMD 5.6K OHM 0.1% 1/10W 0603 | 1 | RG16P5.6KBCT-ND | 0.50000 | $0.50 | 3
ERA-3AEB512V | Panasonic Electronic Components | RES SMD 5.1K OHM 0.1% 1/10W 0603 | 2 | P5.1KDBCT-ND | 0.35000 | $0.70 | 6
CPF0603B10KE1 | TE Connectivity Passive Product | RES SMD 10K OHM 0.1% 1/16W 0603 | 1 | A102331CT-ND | 0.67000 | $0.67 | 3
ESR03EZPF1001 | Rohm Semiconductor | RES SMD 1K OHM 1% 1/4W 0603 | 2 | RHM1.00KADCT-ND | 0.15000 | $0.30 | 6
CRM0805-FX-51R0ELF | Bourns Inc. | RES SMD 51 OHM 1% 1/4W 0805 | 2 | CRM0805-FX-51R0ELFCT-ND | 0.10000 | $0.20 | 6
RK73H2ATTD30R0F | KOA Speer Electronics, Inc. | RES 30 OHM 1% 1/4W 0805 | 2 | 2019-RK73H2ATTD30R0FCT-ND | 0.10000 | $0.20 | 6
RK73H2ATTD1100F | KOA Speer Electronics, Inc. | RES 110 OHM 1% 1/4W 0805 | 4 | 2019-RK73H2ATTD1100FCT-ND | 0.10000 | $0.40 | 12
RK73H2ATTD2700F | KOA Speer Electronics, Inc. | RES 270 OHM 1% 1/4W 0805 | 1 | 2019-RK73H2ATTD2700FCT-ND | 0.10000 | $0.10 | 3
CL21B105KAFNNNE | Samsung Electro-Mechanics | CAP CER 1UF 25V X7R 0805 | 2 | 1276-1066-1-ND | 0.10000 | $0.20 | 6

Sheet: OTS_Button
Manufacturer Part Number | Manufacturer Name | Description | Requested Quantity 1 | Digi-Key Part Number 1 | Unit Price 1 | Extended Price 1 | TotalQTY | Multiplier
W25Q128JVSIQ | Winbond Electronics | IC FLASH 128MBIT SPI/QUAD 8SOIC | 1 | W25Q128JVSIQ-ND | 1.88000 | $1.88 | 3 | 3
NCP1117DTARKG | onsemi | IC REG LINEAR POS ADJ 1A DPAK | 1 | NCP1117DTARKGOSCT-ND | 0.63000 | $0.63 | 3
SC0914(7) | Raspberry Pi | RP2040TR7 | 1 | 2648-SC0914(7)CT-ND | 1.00000 | $1.00 | 3
ABLS-12.000MHZ-B4-T | Abracon LLC | CRYSTAL 12.0000MHZ 18PF SMD | 1 | 535-10218-1-ND | 0.32000 | $0.32 | 3
A-CSL-S-020-B7-A | Assmann WSW Components | CONN PIN SPRING LOAD 5.207MM AU | 6 | AE11599-ND | 0.78000 | $4.68 | 18
RNCP0805FTD150R | Stackpole Electronics Inc | RES 150 OHM 1% 1/4W 0805 | 1 | RNCP0805FTD150RCT-ND | 0.10000 | $0.10 | 3
RK73H2ATTD91R0F | KOA Speer Electronics, Inc. | RES 91 OHM 1% 1/4W 0805 | 2 | 2019-RK73H2ATTD91R0FCT-ND | 0.10000 | $0.20 | 6
CRGP0603F27R | TE Connectivity Passive Product | RES 27 OHM 1% 1/4W 0603 | 2 | A130397CT-ND | 0.18000 | $0.36 | 6
ERA-3AEB512V | Panasonic Electronic Components | RES SMD 5.1K OHM 0.1% 1/10W 0603 | 2 | P5.1KDBCT-ND | 0.35000 | $0.70 | 6
CPF0603B10KE1 | TE Connectivity Passive Product | RES SMD 10K OHM 0.1% 1/16W 0603 | 2 | A102331CT-ND | 0.67000 | $1.34 | 6
CL21B104KACNNNC | Samsung Electro-Mechanics | CAP CER 0.1UF 25V X7R 0805 | 10 | 1276-1099-1-ND | 0.04000 | $0.40 | 30
CL21B105KAFNNNE | Samsung Electro-Mechanics | CAP CER 1UF 25V X7R 0805 | 1 | 1276-1066-1-ND | 0.10000 | $0.10 | 3
RG1608P-562-B-T5 | Susumu | RES SMD 5.6K OHM 0.1% 1/10W 0603 | 1 | RG16P5.6KBCT-ND | 0.50000 | $0.50 | 3
ESR03EZPF1001 | Rohm Semiconductor | RES SMD 1K OHM 1% 1/4W 0603 | 2 | RHM1.00KADCT-ND | 0.15000 | $0.30 | 6
CL21C270JCANNNC | Samsung Electro-Mechanics | CAP CER 27PF 100V C0G/NP0 0805 | 2 | 1276-2622-1-ND | 0.10000 | $0.20 | 6
CL31B106KQHNFNE | Samsung Electro-Mechanics | CAP CER 10UF 6.3V X7R 1206 | 2 | 1276-3107-1-ND | 0.18000 | $0.36 | 6
JMK316BBJ107MLHT | Taiyo Yuden | CAP CER 100UF 6.3V X5R 1206 | 2 | 587-3716-1-ND | 0.72000 | $1.44 | 6

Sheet: OTS_Wires
Manufacturer Part Number | Manufacturer Name | Description | Requested Quantity 1 | Digi-Key Part Number 1 | Unit Price 1 | Extended Price 1 | TotalQTY | Multiplier
JMK316BBJ107MLHT | Taiyo Yuden | CAP CER 100UF 6.3V X5R 1206 | 2 | 587-3716-1-ND | 0.72000 | $1.44 | 6 | 3
CL31B106KQHNFNE | Samsung Electro-Mechanics | CAP CER 10UF 6.3V X7R 1206 | 2 | 1276-3107-1-ND | 0.18000 | $0.36 | 6
CL21B104KACNNNC | Samsung Electro-Mechanics | CAP CER 0.1UF 25V X7R 0805 | 10 | 1276-1099-1-ND | 0.04000 | $0.40 | 30
CL21B105KAFNNNE | Samsung Electro-Mechanics | CAP CER 1UF 25V X7R 0805 | 2 | 1276-1066-1-ND | 0.10000 | $0.20 | 6
CL21C270JCANNNC | Samsung Electro-Mechanics | CAP CER 27PF 100V C0G/NP0 0805 | 2 | 1276-2622-1-ND | 0.10000 | $0.20 | 6
A-CSL-S-020-B7-A | Assmann WSW Components | CONN PIN SPRING LOAD 5.207MM AU | 6 | AE11599-ND | 0.78000 | $4.68 | 18
RG1608P-562-B-T5 | Susumu | RES SMD 5.6K OHM 0.1% 1/10W 0603 | 1 | RG16P5.6KBCT-ND | 0.50000 | $0.50 | 3
CPF0603B10KE1 | TE Connectivity Passive Product | RES SMD 10K OHM 0.1% 1/16W 0603 | 1 | A102331CT-ND | 0.67000 | $0.67 | 3
ERA-3AEB512V | Panasonic Electronic Components | RES SMD 5.1K OHM 0.1% 1/10W 0603 | 2 | P5.1KDBCT-ND | 0.35000 | $0.70 | 6
ESR03EZPF1001 | Rohm Semiconductor | RES SMD 1K OHM 1% 1/4W 0603 | 2 | RHM1.00KADCT-ND | 0.15000 | $0.30 | 6
CRGP0603F27R | TE Connectivity Passive Product | RES 27 OHM 1% 1/4W 0603 | 2 | A130397CT-ND | 0.18000 | $0.36 | 6
RK73H2ATTD91R0F | KOA Speer Electronics, Inc. | RES 91 OHM 1% 1/4W 0805 | 2 | 2019-RK73H2ATTD91R0FCT-ND | 0.10000 | $0.20 | 6
RNCP0805FTD150R | Stackpole Electronics Inc | RES 150 OHM 1% 1/4W 0805 | 1 | RNCP0805FTD150RCT-ND | 0.10000 | $0.10 | 3
NCP1117DTARKG | onsemi | IC REG LINEAR POS ADJ 1A DPAK | 1 | NCP1117DTARKGOSCT-ND | 0.63000 | $0.63 | 3
W25Q128JVSIQ | Winbond Electronics | IC FLASH 128MBIT SPI/QUAD 8SOIC | 1 | W25Q128JVSIQ-ND | 1.88000 | $1.88 | 3
SC0914(7) | Raspberry Pi | RP2040TR7 | 1 | 2648-SC0914(7)CT-ND | 1.00000 | $1.00 | 3
ABLS-12.000MHZ-B4-T | Abracon LLC | CRYSTAL 12.0000MHZ 18PF SMD | 1 | 535-10218-1-ND | 0.32000 | $0.32 | 3

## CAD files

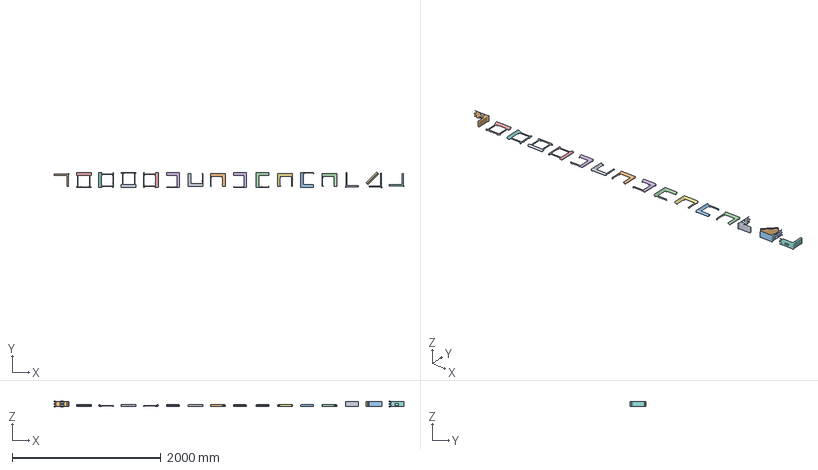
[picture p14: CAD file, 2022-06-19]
Frame v26.3mf
4701.1 x 210.0 x 71.1 mm
Bottom Back Mid
Bottom Back Right
Bottom Back left
Bottom Front Left
Bottom Front Mid
Bottom Front Right
Mid Back Mid
Mid Back Left
Mid Front Right x 2
Mid Front Mid
Top Back Left
Top Back Mid
Top Back Right
Top Front Left
Top Front Mid
Top Front Right
Mid Back Right

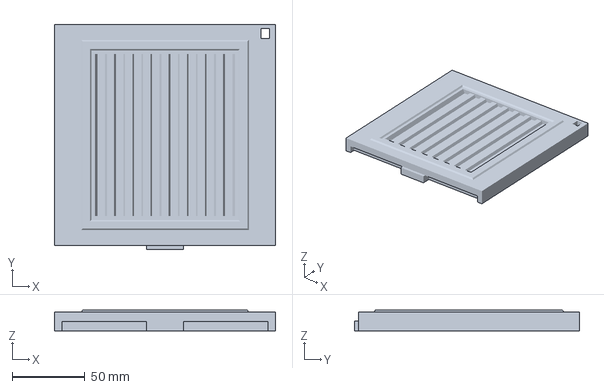
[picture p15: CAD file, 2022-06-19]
Modules/src/basemodule/ArtBlank Filler.3mf
152.4 x 154.9 x 14.2 mm

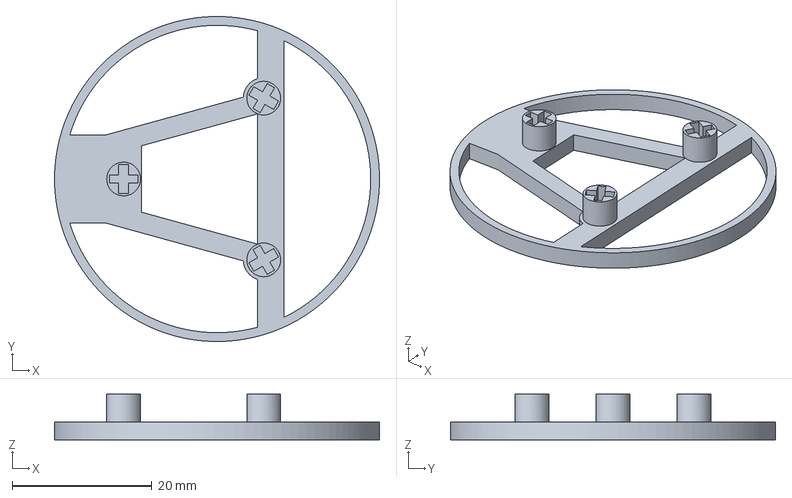
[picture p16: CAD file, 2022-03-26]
Modules/src/OTS_Button/OTS_Button Switch to button chassis .3mf
46.6 x 46.6 x 6.54 mm

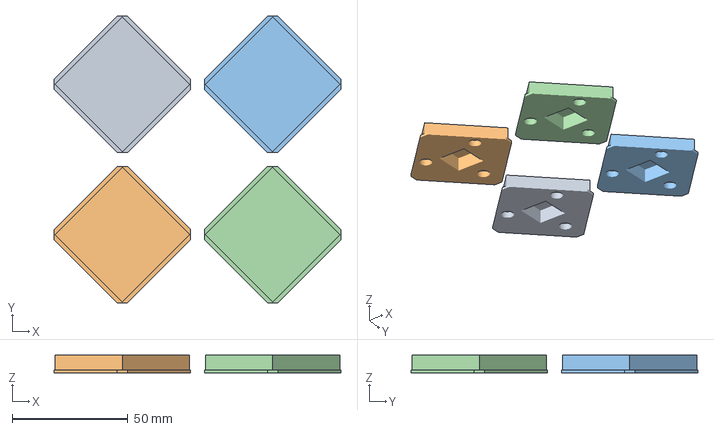
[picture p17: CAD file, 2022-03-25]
Modules/src/OTS_Simon/OTS_Simon Buttons.3mf
124.0 x 124.0 x 7.62 mm

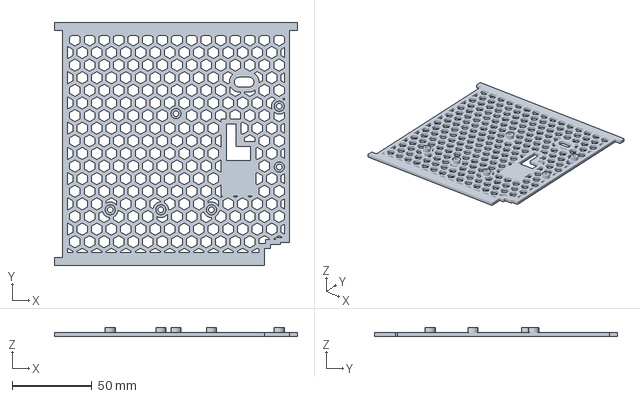
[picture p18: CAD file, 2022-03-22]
Modules/src/OTS_Wires/OTS_Wires Bottom Cover.3mf
152.4 x 152.4 x 5.84 mm

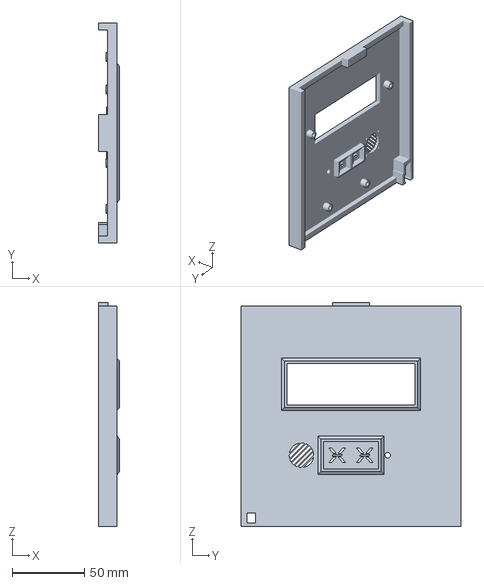
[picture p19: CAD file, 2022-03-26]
rpi_software/controller/ShieldTest/MKTNE_RPI_Shield Top Cover.3mf
14.8 x 152.4 x 154.9 mm

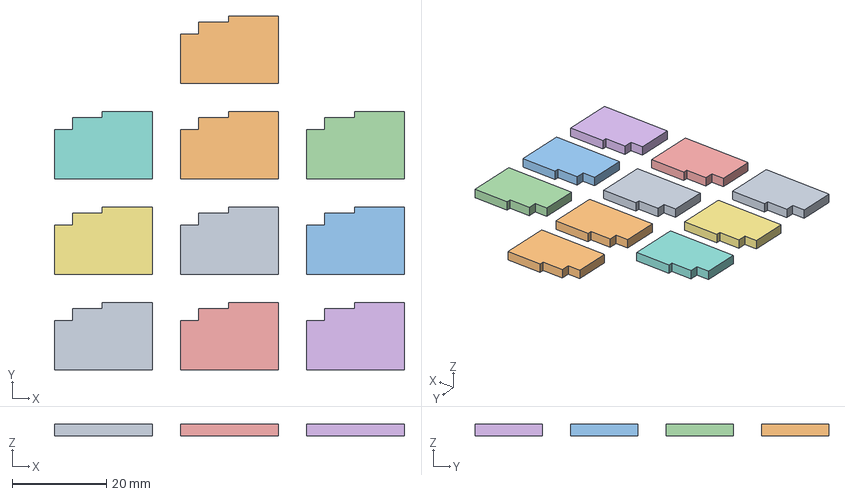
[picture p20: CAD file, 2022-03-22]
Modules/src/basemodule/Spring Cover.3mf
74.5 x 75.3 x 2.54 mm

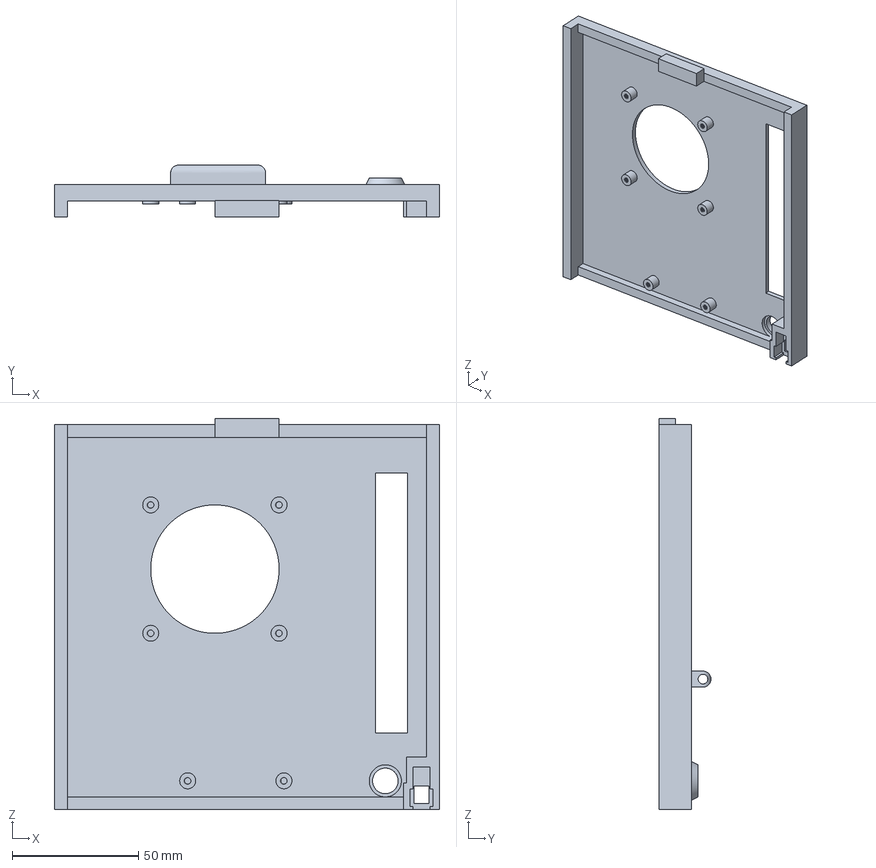
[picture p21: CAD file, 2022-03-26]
Modules/src/OTS_Button/OTS_Button Top Case.3mf
152.4 x 20.6 x 154.9 mm

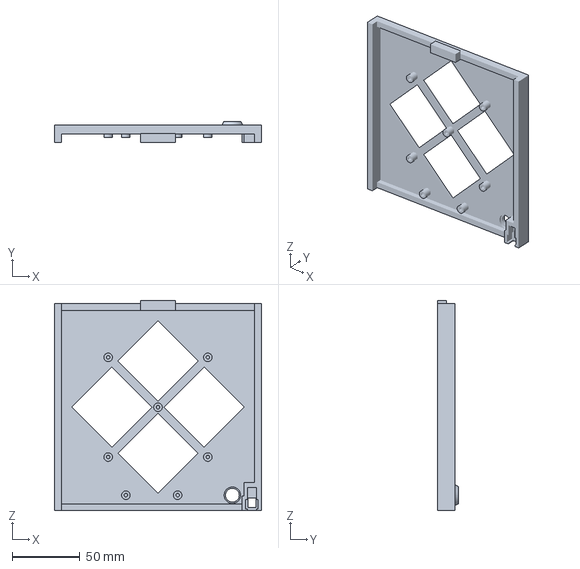
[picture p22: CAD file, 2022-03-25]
Modules/src/OTS_Simon/OTS_Simon Top Case.3mf
152.4 x 15.5 x 154.9 mm

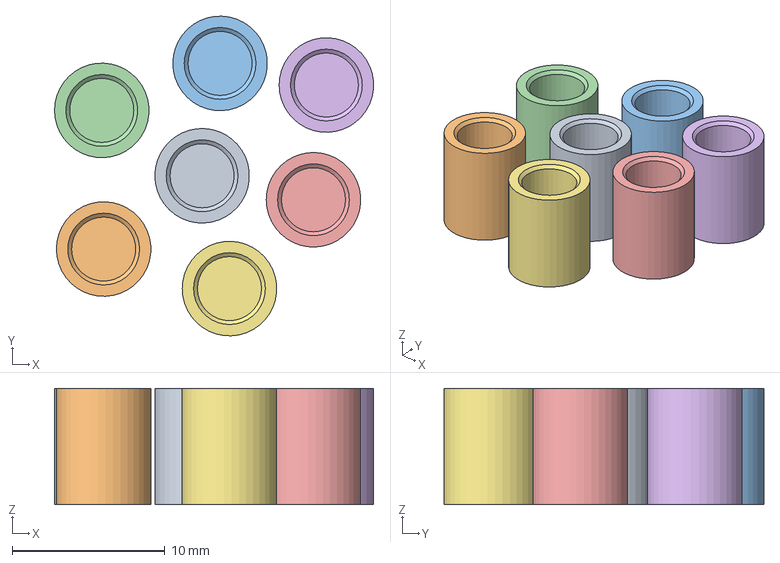
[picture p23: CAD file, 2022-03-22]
Modules/src/OTS_Wires/OTS_Wires Pipe Couplers.3mf
20.9 x 21.0 x 7.62 mm

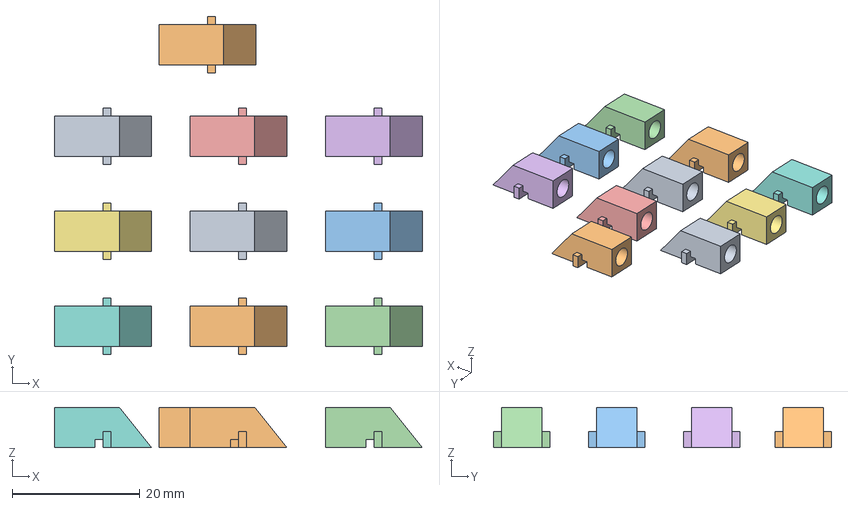
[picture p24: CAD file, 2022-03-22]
Modules/src/basemodule/Locking Pawl.3mf
57.7 x 53.0 x 6.35 mm

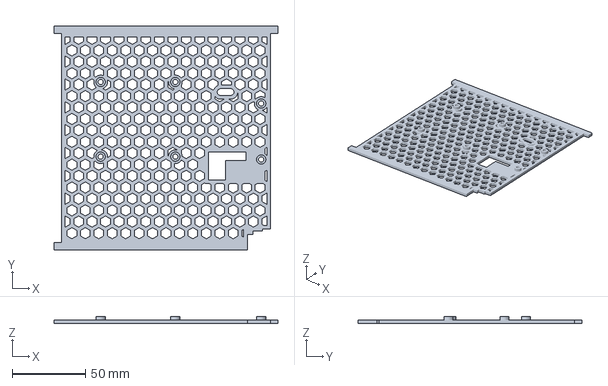
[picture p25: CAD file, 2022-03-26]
Modules/src/OTS_Button/OTS_Button Bottom Cover.3mf
152.4 x 152.4 x 5.08 mm

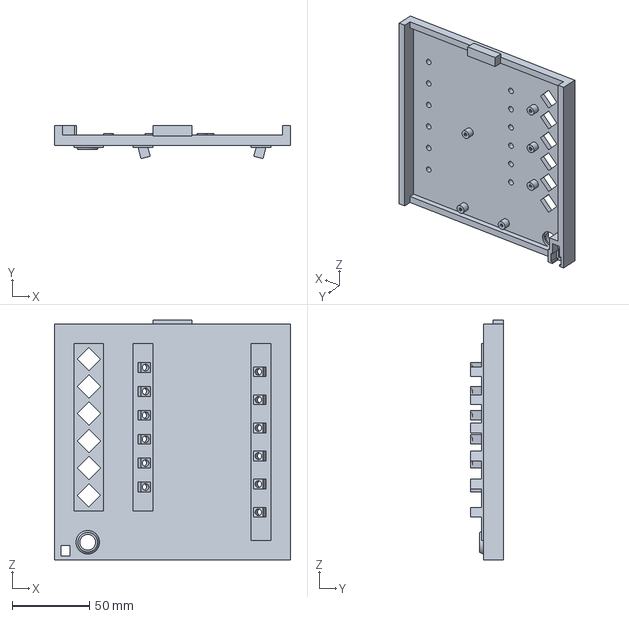
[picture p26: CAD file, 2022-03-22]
Modules/src/OTS_Wires/OTS_Wires Top Body.3mf
152.4 x 21.6 x 154.9 mm

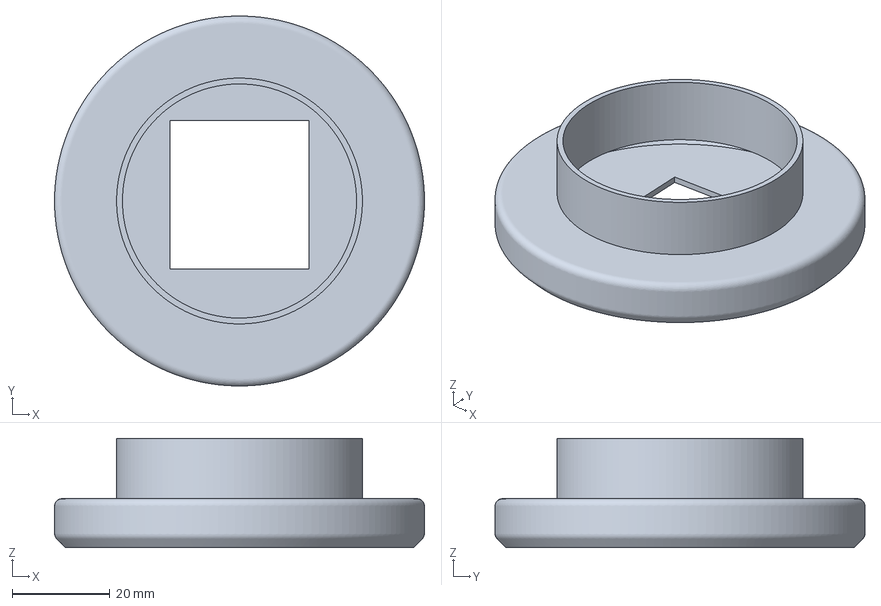
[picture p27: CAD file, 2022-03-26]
Modules/src/OTS_Button/OTS_Button Buttton Chasis.3mf
75.7 x 75.7 x 22.4 mm

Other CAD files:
Modules/src/OTS_Simon/OTS_Simon Back Cover.3mf
Modules/src/OTS_Wires/OTS_Wires Cut Buttons.3mf
Modules/src/OTS_Wires/OTS_Wires 3D Files.f3d
rpi_software/controller/ShieldTest/MKTNE_RPI_Shield 3d Files.f3d

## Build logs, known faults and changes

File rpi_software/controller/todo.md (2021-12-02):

# To Do
- [X] Add MFB processing
    - long press system shutdown (5 seconds)
    - short press random start
- [X] Add Game Logic Control loop
- [X] Add Random Generation command
- [X] Add more details to the game timer function
- [ ] Copy methodology from this timer function to the module c code
- [ ] Add side panel art calls
- [X] Add Damon main file

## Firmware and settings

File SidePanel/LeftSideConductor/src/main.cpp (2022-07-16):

#include <SPI.h>
#include <GxEPD2_3C.h>
#include <Fonts/FreeMonoBold18pt7b.h>
#include <ArduinoJson.h>
#include <Adafruit_GFX.h>
#include "BatteryPictures.h"
#include "PortPictures.h"

/// Buffers and data tracking for I2C communication
byte incomeingI2CData[15];
byte outgoingI2CData[10];
uint8_t bytesToSend = 0;
uint8_t bytesReceived = 0;

#define PCB_VERSION 1

#if PCB_VERSION == 1
#define EPD_RESET_PIN 5
#define EPD_DC_PIN 4
#define EPD_MOSI_PIN 3
#define EPD_SCK_PIN 2
#define EPD_BUS_PIN 18
#define DSP0_CS_PIN 6
#define DSP0_LED_PIN 7
#define DSP1_CS_PIN 14
#define DSP1_LED_PIN 9
#define DSP2_CS_PIN 10
#define DSP3_CS_PIN 11
#define DSP4_CS_PIN 12
#define DSP4_LED_PIN 13
#define DSP5_CS_PIN 8
#define DSP5_LED_PIN 15
#define S2S_SERIAL_RX 17
#define S2S_SERIAL_TX 16
#define CONTROLLER_I2C_SCL 1
#define CONTROLLER_I2C_SDA 0
#elif PCB_VERSION == 2
#define EPD_RESET_PIN 5
#define EPD_DC_PIN 4
#define EPD_MOSI_PIN 3
#define EPD_SCK_PIN 2
#define EPD_BUS_PIN 18
#define DSP0_CS_PIN 6
#define DSP0_LED_PIN 7
#define DSP1_CS_PIN 8
#define DSP1_LED_PIN 9
#define DSP2_CS_PIN 10
#define DSP3_CS_PIN 11
#define DSP4_CS_PIN 12
#define DSP4_LED_PIN 13
#define DSP5_CS_PIN 14
#define DSP5_LED_PIN 15
#define S2S_SERIAL_RX 17
#define S2S_SERIAL_TX 16
#define CONTROLLER_I2C_SCL 1
#define CONTROLLER_I2C_SDA 0
#endif

#define I2C_ADDRESS 0x50
#define S2S_SERIAL_SPEED 115200

GxEPD2_290_C90c IndicatorDSP0(/*CS=*/DSP0_CS_PIN, /*DC=*/EPD_DC_PIN, -1, /*BUSY=*/EPD_BUS_PIN); // Indicator
GxEPD2_290_C90c IndicatorDSP1(/*CS=*/DSP1_CS_PIN, /*DC=*/EPD_DC_PIN, -1, /*BUSY=*/EPD_BUS_PIN); // Ind
GxEPD2_290_C90c ArtDSP0(/*CS=*/DSP2_CS_PIN, /*DC=*/EPD_DC_PIN, -1, /*BUSY=*/EPD_BUS_PIN);
GxEPD2_290_C90c ArtDSP1(/*CS=*/DSP3_CS_PIN, /*DC=*/EPD_DC_PIN, -1, /*BUSY=*/EPD_BUS_PIN);
GxEPD2_290_C90c IndicatorDSP2(/*CS=*/DSP4_CS_PIN, /*DC=*/EPD_DC_PIN, -1, /*BUSY=*/EPD_BUS_PIN);
GxEPD2_290_C90c IndicatorDSP3(/*CS=*/DSP5_CS_PIN, /*DC=*/EPD_DC_PIN, -1, /*BUSY=*/EPD_BUS_PIN);

GFXcanvas1 BlackCanvas(IndicatorDSP0.WIDTH, IndicatorDSP0.HEIGHT);
GFXcanvas1 RedCanvas(IndicatorDSP0.WIDTH, IndicatorDSP0.HEIGHT);

// Tracking Variables
uint8_t indiNumber = 0;
uint8_t artNumber = 0;
const uint8_t ARTDSPRANGE[] = {1, 5};
const uint8_t MAXDSPNUM = ARTDSPRANGE[1];
uint8_t batDSPDrawCycle = 0;
uint8_t portDSPDrawCycle = 0;
uint8_t indiMap[] = {0, 1, 2, 3, 4, 5};
uint8_t artMap[] = {0, 1, 2, 3};

// Initializes and clears the connected displays
void setupDisplays()
{
  // Setup DSP Pins
  pinMode(EPD_RESET_PIN, OUTPUT);
  pinMode(EPD_DC_PIN, OUTPUT);
  pinMode(DSP0_CS_PIN, OUTPUT);
  pinMode(DSP1_CS_PIN, OUTPUT);
  pinMode(DSP2_CS_PIN, OUTPUT);
  pinMode(DSP3_CS_PIN, OUTPUT);
  pinMode(DSP4_CS_PIN, OUTPUT);
  pinMode(DSP5_CS_PIN, OUTPUT);
  pinMode(EPD_BUS_PIN, INPUT);

  // Setup LED Pins
  pinMode(DSP0_LED_PIN, OUTPUT);
  pinMode(DSP1_LED_PIN, OUTPUT);
  pinMode(DSP4_LED_PIN, OUTPUT);
  pinMode(DSP5_LED_PIN, OUTPUT);

  // Release All Displays
  digitalWrite(DSP0_CS_PIN, true);
  digitalWrite(DSP1_CS_PIN, true);
  digitalWrite(DSP2_CS_PIN, true);
  digitalWrite(DSP3_CS_PIN, true);
  digitalWrite(DSP4_CS_PIN, true);
  digitalWrite(DSP5_CS_PIN, true);

  // Reset All Displays
  // Serial.println("DSP RESET");
  digitalWrite(EPD_RESET_PIN, true);
  delay(100);
  digitalWrite(EPD_RESET_PIN, false);
  delay(100);
  digitalWrite(EPD_RESET_PIN, true);

  // Init and attempt to fill the displays buffers
  // Serial.println("DSP INIT");
  IndicatorDSP0.init();
  IndicatorDSP0.writeScreenBuffer(GxEPD_WHITE);
  IndicatorDSP1.init();
  IndicatorDSP1.writeScreenBuffer(GxEPD_WHITE);
  ArtDSP0.init();
  ArtDSP0.writeScreenBuffer(GxEPD_WHITE);
  ArtDSP1.init();
  ArtDSP1.writeScreenBuffer(GxEPD_WHITE);
  IndicatorDSP2.init();
  IndicatorDSP2.writeScreenBuffer(GxEPD_WHITE);
  IndicatorDSP3.init();
  IndicatorDSP3.writeScreenBuffer(GxEPD_WHITE);

  // Grab all dislays and clear them then release them
  digitalWrite(DSP0_CS_PIN, false);
  digitalWrite(DSP1_CS_PIN, false);
  digitalWrite(DSP2_CS_PIN, false);
  digitalWrite(DSP3_CS_PIN, false);
  digitalWrite(DSP4_CS_PIN, false);
  digitalWrite(DSP5_CS_PIN, false);
  // IndicatorDSP0.clearScreen(GxEPD_WHITE);
  digitalWrite(DSP0_CS_PIN, true);
  digitalWrite(DSP1_CS_PIN, true);
  digitalWrite(DSP2_CS_PIN, true);
  digitalWrite(DSP3_CS_PIN, true);
  digitalWrite(DSP4_CS_PIN, true);
  digitalWrite(DSP5_CS_PIN, true);

  delay(10);
}

void drawDisplays()
{
  digitalWrite(DSP0_CS_PIN, false);
  digitalWrite(DSP1_CS_PIN, false);
  digitalWrite(DSP2_CS_PIN, false);
  digitalWrite(DSP3_CS_PIN, false);
  digitalWrite(DSP4_CS_PIN, false);
  digitalWrite(DSP5_CS_PIN, false);
  IndicatorDSP0.refresh();
  digitalWrite(DSP0_CS_PIN, true);
  digitalWrite(DSP1_CS_PIN, true);
  digitalWrite(DSP2_CS_PIN, true);
  digitalWrite(DSP3_CS_PIN, true);
  digitalWrite(DSP4_CS_PIN, true);
  digitalWrite(DSP5_CS_PIN, true);
}

// Draws a Battery to the specified display
// True is AA false is D
void writeBattery(uint8_t displayNum, bool AAorD)
{
  // Code needs to be updated to support multiple displays
  // displays[displayNum].fillScreen(GxEPD_WHITE);
  if (displayNum < 2)
  {
    BlackCanvas.fillScreen(GxEPD_WHITE);
    RedCanvas.fillScreen(GxEPD_WHITE);
    if (AAorD)
    {
      BlackCanvas.drawBitmap(0, 6, epd_bitmap_AA_Black, epd_bitmap_AA_size[0], epd_bitmap_AA_size[1], GxEPD_BLACK);
      RedCanvas.drawBitmap(0, 6, epd_bitmap_AA_Red, epd_bitmap_AA_size[0], epd_bitmap_AA_size[1], GxEPD_BLACK);
    }
    else
    {
      BlackCanvas.drawBitmap(0, 6, epd_bitmap_D_Black, epd_bitmap_D_size[0], epd_bitmap_D_size[1], GxEPD_BLACK);
      RedCanvas.drawBitmap(0, 6, epd_bitmap_D_Red, epd_bitmap_D_size[0], epd_bitmap_D_size[1], GxEPD_BLACK);
    }
  }

  switch (displayNum)
  {
  case 0:
    ArtDSP0.writeScreenBuffer(GxEPD_WHITE);
    ArtDSP0.writeImage(BlackCanvas.getBuffer(), RedCanvas.getBuffer(), 0, 0, 128, 256, true, false, false);
    break;
  case 1:
    ArtDSP1.writeScreenBuffer(GxEPD_WHITE);
    ArtDSP1.writeImage(BlackCanvas.getBuffer(), RedCanvas.getBuffer(), 0, 0, 128, 256, true, false, false);
    break;
  }
}

// Draws the SerialNumber to dsp 0
void writeSerialNum(String text)
{
  DynamicJsonDocument doc(60);
  doc["command"] = "serial";
  doc["serial"] = text;
  Serial1.println(serializeJson(doc, Serial));
}

// Draws the SerialNumber to dsp 0
// Overload for a char array instead of a string
void writeSerialNum(char intext[])
{
  String strtext = intext;
  writeSerialNum(strtext);
}

// Draws a port to the specified display
// Host is responsible for avoiding collisions, bad data will not be drawn but there might be a missing port caused by a collision
void writePort(uint8_t displayNum, byte activeports)
{
  // 1 = Port
  // 0 = not used
  // 1 = DVI
  // 1 = Parallel
  // 1 = PS/2
  // 1 = RJ45
  // 1 = Serial
  // 1 = SteroRCA
  bool dviActive = activeports & 0b00100000;
  bool parallelActive = activeports & 0b00010000;
  bool ps2Active = activeports & 0b00001000;
  bool rj45Active = activeports & 0b00000100;
  bool serialActive = activeports & 0b00000010;
  bool rcaActive = activeports & 0b00000001;
  // Code needs to be updated to support multiple displays
  // displays[displayNum].fillScreen(GxEPD_WHITE);
  const uint8_t VAL_TO_ADD = 67;

  if (displayNum < 2)
  { // If the display number is on the Conductor node populate the display with the correct artwork
    BlackCanvas.fillScreen(GxEPD_WHITE);
    RedCanvas.fillScreen(GxEPD_WHITE);
    uint8_t longporty = 6;
    uint8_t shortportx = 0;
    if (rj45Active)
    {
      BlackCanvas.drawBitmap(shortportx, 6, epd_bitmap_rj45_Black, epd_bitmap_rj45_size[0], epd_bitmap_rj45_size[1], GxEPD_BLACK);
      longporty += VAL_TO_ADD;
      shortportx += epd_bitmap_rj45_size[0] + 5;
    }
    if (ps2Active)
    {
      BlackCanvas.drawBitmap(shortportx, 6, epd_bitmap_PS2_Black, epd_bitmap_PS2_size[0], epd_bitmap_PS2_size[1], GxEPD_BLACK);
      if (longporty < 30)
      {
        longporty += VAL_TO_ADD;
      }
      shortportx += epd_bitmap_PS2_size[0] + 5;
    }
    if (rcaActive)
    {
      BlackCanvas.drawBitmap(198, 6, epd_bitmap_RCA_Black, epd_bitmap_RCA_size[0], epd_bitmap_RCA_size[1], GxEPD_BLACK);
      RedCanvas.drawBitmap(198, 6, epd_bitmap_RCA_Red, epd_bitmap_RCA_size[0], epd_bitmap_RCA_size[1], GxEPD_BLACK);
    }
    bool pass = false;
    if (dviActive)
    {
      BlackCanvas.drawBitmap(0, longporty, epd_bitmap_DVI_Black, epd_bitmap_DVI_size[0], epd_bitmap_DVI_size[1], GxEPD_BLACK);
      if (longporty > 30)
      {
        pass = true;
      }
      else
      {
        longporty += VAL_TO_ADD;
      }
    }
    if (serialActive && !pass)
    {
      BlackCanvas.drawBitmap(0, longporty, epd_bitmap_Serial_Black, epd_bitmap_Serial_size[0], epd_bitmap_Serial_size[1], GxEPD_BLACK);
      if (longporty > 30)
      {
        pass = true;
      }
      else
      {
        longporty += VAL_TO_ADD;
      }
    }
    if (parallelActive && !rcaActive && !pass)
    {
      BlackCanvas.drawBitmap(0, longporty, epd_bitmap_Parallel_Black, epd_bitmap_Parallel_size[0], epd_bitmap_Parallel_size[1], GxEPD_BLACK);
    }
    switch (displayNum)
    {
    case 0:
      ArtDSP0.writeScreenBuffer(GxEPD_WHITE);
      ArtDSP0.writeImage(BlackCanvas.getBuffer(), RedCanvas.getBuffer(), 0, 0, 128, 256, false, false, false);
      break;
    case 1:
      ArtDSP1.writeScreenBuffer(GxEPD_WHITE);
      ArtDSP1.writeImage(BlackCanvas.getBuffer(), RedCanvas.getBuffer(), 0, 0, 128, 256, false, false, false);
      break;
    }
  }
}

void writeIndicator(uint8_t indiNumber, bool lit, char *lbl)
{
  if (indiNumber < 4)
  {
    BlackCanvas.fillScreen(GxEPD_WHITE);
    BlackCanvas.setCursor(-2, 98);
    BlackCanvas.setTextColor(GxEPD_BLACK);
    BlackCanvas.setFont(&FreeMonoBold18pt7b);
    BlackCanvas.setTextSize(4);
    BlackCanvas.print(lbl);
  }
  DynamicJsonDocument doc(60);
  switch (indiNumber)
  {
  case 0:
    IndicatorDSP0.writeScreenBuffer(GxEPD_WHITE);
    IndicatorDSP0.writeImage(BlackCanvas.getBuffer(), NULL, 0, 0, 128, 256, false, false, false);
    digitalWrite(DSP0_LED_PIN, lit);
    break;
  case 1:
    IndicatorDSP1.writeScreenBuffer(GxEPD_WHITE);
    IndicatorDSP1.writeImage(BlackCanvas.getBuffer(), NULL, 0, 0, 128, 256, false, false, false);
    digitalWrite(DSP1_LED_PIN, lit);
    break;
  case 2:
    IndicatorDSP2.writeScreenBuffer(GxEPD_WHITE);
    IndicatorDSP2.writeImage(BlackCanvas.getBuffer(), NULL, 0, 0, 128, 256, false, false, false);
    digitalWrite(DSP4_LED_PIN, lit);
    break;
  case 3:
    IndicatorDSP3.writeScreenBuffer(GxEPD_WHITE);
    IndicatorDSP3.writeImage(BlackCanvas.getBuffer(), NULL, 0, 0, 128, 256, false, false, false);
    digitalWrite(DSP5_LED_PIN, lit);
    break;
  case 4:
    doc["command"] = "indicator";
    doc["display"] = 4;
    doc["label"] = lbl;
    doc["lit"] = lit;
    Serial1.println(serializeJson(doc, Serial1));
    break;
  case 5:
    doc["command"] = "indicator";
    doc["display"] = 5;
    doc["label"] = lbl;
    doc["lit"] = lit;
    Serial1.println(serializeJson(doc, Serial1));
    break;
  }
}

// Clear a EPD DSP
void clearEPDDSPS()
{
  digitalWrite(DSP0_CS_PIN, false);
  digitalWrite(DSP1_CS_PIN, false);
  digitalWrite(DSP2_CS_PIN, false);
  digitalWrite(DSP3_CS_PIN, false);
  digitalWrite(DSP4_CS_PIN, false);
  digitalWrite(DSP5_CS_PIN, false);
  IndicatorDSP1.clearScreen(GxEPD_WHITE);
  digitalWrite(DSP0_CS_PIN, true);
  digitalWrite(DSP1_CS_PIN, true);
  digitalWrite(DSP2_CS_PIN, true);
  digitalWrite(DSP3_CS_PIN, true);
  digitalWrite(DSP4_CS_PIN, true);
  digitalWrite(DSP5_CS_PIN, true);

  digitalWrite(DSP0_LED_PIN, false);
  digitalWrite(DSP1_LED_PIN, false);
  digitalWrite(DSP4_LED_PIN, false);
  digitalWrite(DSP5_LED_PIN, false);

  Serial1.println("{\"Clear\":\"All\"}");
}

void randomizeDSPS()
{
  for (int i = 6; i > 0; i--) {
    indiMap[i-1] = 10;
  } 
  for (int i = 6; i > 0; i--) {
    bool Stashed = false;
    while (!Stashed) {
      int r = random(4);
      if (indiMap[r] == 10) {
        indiMap[r] = i-1;
        Stashed = true;
      }
    }
  }
  for (int i = 4; i > 0; i--) {
    artMap[i-1] = 10;
  }
  for (int i = 4; i > 0; i--) {
    bool Stashed = false;
    while (!Stashed) {
      int r = random(4);
      if (artMap[r] == 10) {
        artMap[r] = i-1;
        Stashed = true;
      }
    }
  }
}

// Determins what art to draw onto the display or to send that code to the follower device
void processSideArt(uint8_t displayNum, byte artcode)
{
  DynamicJsonDocument doc(60);
  switch (displayNum)
  {
  case 0:
  case 1:
    // first bit equals art type Battery or Port
    // 0 = Battery
    // 1 = Port
    {
      bool artType = artcode & 0b10000000;
      if (artType)
      {
        writePort(displayNum, artcode);
      }
      else
      {
        // Battery
        // 0 = Battery
        // 0 = not used
        // 0 = not used
        // 0 = not used
        // 0 = not used
        // 0 = not used
        // 0 = not used
        // 1 = 1 is AA  0 is D
        bool AAorD = artcode & 0b000000001;
        writeBattery(displayNum, AAorD);
      }
    }
    break;
  case 2:
    doc["command"] = "art";
    doc["display"] = 2;
    doc["artcode"] = artcode;
    Serial1.println(serializeJson(doc, Serial1));
    break;
  case 3:
    doc["command"] = "art";
    doc["display"] = 3;
    doc["artcode"] = artcode;
    Serial1.println(serializeJson(doc, Serial1));
    break;
  }
}

// Sends out our output buffer
void requestEvent()
{
  if (bytesToSend > 0)
  {
    Wire.write(outgoingI2CData, bytesToSend);
  }
  bytesToSend = 0;
}

// Copy the incoming data into our input buffer
void receiveEvent(int numBytes)
{
  bytesReceived = numBytes;
  for (int i = 0; i < numBytes; i++)
  {
    if (i > 10)
    {
      Wire.read();
    }
    else
    {
      incomeingI2CData[i] = Wire.read();
    }
  }
}

// Process the incoming data
void I2CCommandProcessor()
{
  switch (incomeingI2CData[0] >> 4)
  {
  case 0x1: // Set
    switch (incomeingI2CData[0] & 0xF)
    {
    case 0x0: // Set Serial Number
      {
        uint32_t command1 = 0x05000000 & (incomeingI2CData[1]);                                                                     // Construct command
        uint32_t data1 = (incomeingI2CData[2]) << 24 & (incomeingI2CData[3] << 16) & (incomeingI2CData[4] << 8) & (incomeingI2CData[5]); // Construct data
        uint32_t data2 = (incomeingI2CData[6]) << 24 & (incomeingI2CData[7] << 16) & (incomeingI2CData[8]) & (incomeingI2CData[9]); // Construct data
        rp2040.fifo.push(command1);                                                                                                 // Send Command
        rp2040.fifo.push(data1);                                                                                                    // Send Data
        rp2040.fifo.push(data2);                                                                                                    // Send Data
      }
      break;
    case 0x1: // Set Indicator
      {
        uint32_t command1 = 0x03000000 & (indiMap[indiNumber] << 16); // Construct Command
        uint32_t indicatorValue = (incomeingI2CData[1] << 24) & (incomeingI2CData[2] << 16) & (incomeingI2CData[3] << 8) & incomeingI2CData[4]; // Construct Indicator Value
        rp2040.fifo.push(command1);                                                                                                 // Send Command
        rp2040.fifo.push(indicatorValue);                                                                                           // Send Indicator Value
        indiNumber++;
      }
      break;
    case 0x2: // Set SideArt
      {
        uint32_t command1 = 0x04000000 & (artMap[artNumber] << 16) & (incomeingI2CData[1] << 8) ; // Construct command
        rp2040.fifo.push(command1); // Send Command
        artNumber++;
      }
      break;
    }
    break;

  case 0x0: // Other Functions
    switch (incomeingI2CData[0] & 0xF)
    {
    case 0x0: // Randomize Art DSP
      randomizeDSPS();
      break;
    case 0x1:
      rp2040.fifo.push(0x02000000); //Draw
      break;
    case 0x2:
      rp2040.fifo.push(0x01000000); //Clear
      artNumber = 0;
      indiNumber = 0;
      break;
    }
  }
}

void setup()
{
  // Seed random
  randomSeed(analogRead(26));

  // Start I2C Communications 
  Wire.setSCL(CONTROLLER_I2C_SCL);
  Wire.setSDA(CONTROLLER_I2C_SDA);
  Wire.begin(I2C_ADDRESS);
  Wire.onReceive(receiveEvent);
  Wire.onRequest(requestEvent);
}

void setup1() {
  // Set SPI Pins
  SPI.setTX(EPD_MOSI_PIN);
  SPI.setSCK(EPD_SCK_PIN);
 // Set S2S Serial
  Serial1.setTX(S2S_SERIAL_TX);
  Serial1.setRX(S2S_SERIAL_RX);
  Serial1.begin(S2S_SERIAL_SPEED);

  BlackCanvas.setRotation(1);
  RedCanvas.setRotation(1);

  // Tell remote to startup
  Serial1.println("{\"command\":\"startup\"}");
  // Startup Own Displays
  setupDisplays();
}

void loop()
{
  I2CCommandProcessor();
}

void loop1()
{
  if (rp2040.fifo.available())
  {
    uint32_t data = rp2040.fifo.pop();
    uint8_t command = (data & 0xFF000000) >> 24;
    uint8_t displayNum = (data & 0x00FF0000) >> 16;
    uint8_t artcode = (data & 0x0000FF00) >> 8;
    uint8_t sparebyte = (data & 0x000000FF);
    switch (command)
    {
    case 0:
      setupDisplays();
      break;
    case 1:
      clearEPDDSPS();
      break;
    case 2:
      drawDisplays();
      break;
    case 3:
      if (rp2040.fifo.available())
      {
        uint32_t data = rp2040.fifo.pop();
        bool lit = (data & 0xFF000000) >> 24;
        char letter1 = (data & 0x00FF0000) >> 16;
        char letter2 = (data & 0x0000FF00) >> 8;
        char letter3 = data & 0x000000FF;
        char lbl[3] = {letter1, letter2, letter3};
        writeIndicator(displayNum, lit, lbl);
      }
      break;
    case 4:
      processSideArt(displayNum, artcode);
      break;
    case 5:
      if (rp2040.fifo.available())
      {
        uint32_t data = rp2040.fifo.pop();
        uint32_t data1 = rp2040.fifo.pop();
        char serialnum[10] = {
            sparebyte,
            (data & 0xFF000000) >> 24,
            (data & 0x00FF0000) >> 16,
            (data & 0x0000FF00) >> 8,
            (data & 0x000000FF),
            (data1 & 0xFF000000) >> 24,
            (data1 & 0x00FF0000) >> 16,
            (data1 & 0x0000FF00) >> 8,
            (data1 & 0x000000FF),
            0x0};
        String serial = String(*serialnum);
        writeSerialNum(serial);
      }
      break;
    }
  }
}

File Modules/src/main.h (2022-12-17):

using namespace std;
#include <Arduino.h>
#include <Wire.h>
#include <SPI.h>

//#define DEBUG_MODE_TIMER
#define TIMER_ENABLE

// ********************************
// Include the type of module that we use
// ********************************
// #include "basemodule/basemodule.h"
// BaseModule mod = BaseModule();
// #include "OTS_Button/OTS_Button.h"
// OTS_Button mod = OTS_Button();
// #include "OTS_Wires/OTS_Wires.h"
// OTS_Wires mod = OTS_Wires();
#include "OTS_Simon/OTS_Simon.h"
OTS_Simon mod = OTS_Simon();


// *************** External Communications Controller/Player *****************
#define AddressInPin A0
#define RandSorcePin 27
#define SuccessLEDPin 8
#define FailureLEDPin 9
#define S2MInteruptPin 4


/// Timekeeping variables for external pins for their reset
unsigned long S2MInteruptCallTime = 0;
unsigned long FailureLEDCallTime = 0;
bool GamePlayLockout = 0;

/// Buffers and data tracking for I2C communication
uint8_t incomeingI2CData[10];
uint8_t outgoingI2CData[10];
uint8_t uint8_tsToSend = 0;
uint8_t uint8_tsReceived = 0;
// **********************************************************************

// In side of the desired module use the following to acctivate the timer
// #define TIMER_ENABLE True

// ************** Default Variable Sizes ******************
#define GAMEPLAYSERIALNUMBERLENGTH 8
#define GAMEPLAYMAXLITINDICATOR 6

// *************** Gameplay Variables *****************
// the specific module  might not use the following variables but they will get set
// by the master controller so we want to keep trac of them for the module specific code
/// each run will have a serial number that is used in that run
char gameplaySerialNumber[GAMEPLAYSERIALNUMBERLENGTH];
/// The device can have a number of lit indicators on the sides but gameplay only cares if they are lit
char gameplayLitIndicators[GAMEPLAYMAXLITINDICATOR][3];
uint8_t gameplayLitIndicatorCount = 0;
/// Most modules will have a seed that it can be set to in order to load a specific module configuration
uint16_t gameplaySeed = 0;
/// Number of battery's that esists on the entire device
uint8_t gameplayNumBattery = 0;
/// There is only six possible ports in the game and they have a bit possition assigned to them.
/// See reference chart in typed notes for more information about which is which
uint8_t gameplayPorts = 0;
/// Timekeeping and gameplay variables
unsigned long gameplayCountdownTime = 0;
bool gameplayTimerRunning = false;
float gameplayStrikeReductionRate = 0.25;
/// All most modules will have a state that they can be set to
/// if a module is failed it will be set to a negative number
/// it will decrement by 1 each time it is failed
int8_t gameplayModuleSolved = 0;
// ****************************************************

uint8_t convertToAddress(uint16_t addrVIn);
void FlagModuleSolved();
void FlagModuleFailed();
#ifdef TIMER_ENABLE
unsigned long timekeeperLastRun = 0;
uint8_t textraCount = 0;
void decrementCounter();
#endif
void requestEvent();
void receiveEvent(int numuint8_ts);
void I2CCommandProcessor();
void setup();
void loop();

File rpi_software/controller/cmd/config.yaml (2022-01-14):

Network:
  MultiCastIP: 228.74.66.248
  MultiCastPort: 26960
Shield:
  I2cBusNumber: 1
  BuzzerPinNum: 18
  Strike1PinNum: 22
  Strike2PinNum: 23
  ModInterruptPinNum: 17
  MfbStartPinNum: 27
  SevenSegAddress: 0x70

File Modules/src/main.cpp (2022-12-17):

#include "main.h"

// I2C from AIN Address Table
uint8_t convertToAddress(uint16_t addrVIn)
{
    // Top
    if (addrVIn >= 93 && addrVIn < 186)
    {
        return 0x30;
    }
    else if (addrVIn >= 186 && addrVIn < 279)
    {
        return 0x31;
    }
    else if (addrVIn >= 279 && addrVIn < 372)
    {
        return 0x32;
    }
    else if (addrVIn >= 372 && addrVIn < 465)
    {
        return 0x33;
    }
    else if (addrVIn >= 465 && addrVIn < 558)
    {
        return 0x34;
    }
    // Bottom
    else if (addrVIn >= 558 && addrVIn < 651)
    {
        return 0x40;
    }
    else if (addrVIn >= 651 && addrVIn < 744)
    {
        return 0x41;
    }
    else if (addrVIn >= 744 && addrVIn < 837)
    {
        return 0x42;
    }
    else if (addrVIn >= 837 && addrVIn < 930)
    {
        return 0x43;
    }
    else if (addrVIn >= 930 && addrVIn <= 1024)
    {
        return 0x44;
    }
    else
    {
        return 0x00;
    }
}

// This function is called when the module code determines that the module has been solved
void FlagModuleSolved()
{
    // Set the module solved flag to 1
    gameplayModuleSolved = 1;
    outgoingI2CData[0] = 0x1;
    // Turn on the success LED
    digitalWrite(SuccessLEDPin, HIGH);
    // Turn off the failure LED
    S2MInteruptCallTime = millis();
    // Turn off the failure LED
    digitalWrite(S2MInteruptPin, LOW);
    gameplayTimerRunning = false;
    mod.clearModule();
    gameplaySeed = 0;
    for (uint8_t i = 0; i < GAMEPLAYSERIALNUMBERLENGTH; i++)
    {
        gameplaySerialNumber[i] = '\0';
    }
    gameplayLitIndicatorCount = 0;
    gameplayStrikeReductionRate = 0.25;
    gameplayNumBattery = 0;
    gameplayPorts = 0;
}

// This function is called when the module code determines that the module has been failed
void FlagModuleFailed()
{
    // Set the module solved flag to -1
    gameplayModuleSolved -= 1;
    mod.setNumStrike(gameplayModuleSolved * -1);
    // Record the on time of the failure LED
    FailureLEDCallTime = millis();
    // Turn on the failure LED
    digitalWrite(FailureLEDPin, HIGH);
    // Record the start of the signal to the controller interupt
    S2MInteruptCallTime = millis();
    // Signal the main controller interupt
    digitalWrite(S2MInteruptPin, LOW);
    GamePlayLockout = true;
}

#ifdef TIMER_ENABLE
// Updates to defused time of the module
void decrementCounter()
{
    if (!gameplayTimerRunning || gameplayModuleSolved > 0)
    {
        return;
    }
    unsigned long currentTime = millis();
    // Calculate how long it has been since the last run
    unsigned long timesincelastrun = currentTime - timekeeperLastRun;
    // Subtrack it out
    gameplayCountdownTime -= timesincelastrun;

    // If we have a strike
    if (gameplayModuleSolved < 0)
    {
        float everyrate = (1 / gameplayStrikeReductionRate) / (gameplayModuleSolved * -1);
        if (textraCount >= everyrate)
        {
            unsigned long textra = everyrate;
            if (everyrate < 1)
            {
                textra += 1 / everyrate;
            }
            textraCount = 0;
            gameplayCountdownTime -= textra;
        }
        else
        {
            if (timesincelastrun >= 1)
            {
                textraCount += 1;
            }
        }
    }
    if (gameplayCountdownTime == 0 || gameplayModuleSolved >= 18000000)
    {
        gameplayModuleSolved = 0;
        gameplayTimerRunning = false;
        FlagModuleFailed();
    }
    timekeeperLastRun = currentTime;

#ifdef DEBUG_MODE_TIMER
    uint16_t hundrethsTime = gameplayCountdownTime / 10;
    uint16_t seconds = gameplayCountdownTime / 1000;
    uint16_t minutes = seconds / 60;

    String ctime = String(minutes) + ":" + String(seconds % 60);
    if (minutes < 1)
    {
        ctime += "." + String(hundrethsTime / 10 % 10) + String(hundrethsTime % 10);
    }
    Serial.print("Time: ");
    Serial.print(ctime);
    Serial.print(", timmil:");
    Serial.println(gameplayCountdownTime);

#endif
}
#endif

// Sends out our output buffer
void requestEvent()
{
    if (uint8_tsToSend > 0)
    {

        Serial.print("Sending: ");
        Serial.println(uint8_tsToSend);

        for (size_t i = 0; i < uint8_tsToSend; i++)
        {
            Wire1.write(outgoingI2CData, uint8_tsToSend);
        }
        uint8_tsToSend = 0;
    }
    else
    {

        Wire1.write(0xFF);
    }
}

// Copy the incoming data into our input buffer
void receiveEvent(int numuint8_ts)
{

    Serial.print("Received: ");
    Serial.println(numuint8_ts);
    for (int i = 0; i < numuint8_ts; i++)
    {
        if (i > 10)
        {
            Wire1.read();
        }
        else
        {
            uint8_t wirein = Wire1.read();
            Serial.print(wirein, HEX);
            Serial.print(" ");
            incomeingI2CData[i] = wirein;

            incomeingI2CData[i] = Wire1.read();
        }
    }
    uint8_tsReceived = numuint8_ts;

    Serial.println();
}
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

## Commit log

2021-10-24 Worked on bugs + I2C command processing
    [KTNE_BasicModule.cpp]
2021-10-26 started inital work on I2C controllers
2021-11-09 Cleaned up simon and added the start of button
2021-11-21 Added button checking
2021-12-02 Started work on controller flowchart diagram
2021-12-18 Updated Timer and jsdecode
2021-12-29 Moved Type, Timer, and netsend to common file
2021-12-29 fixed tmr and added exit case
2022-01-08 Added the start of the helper functions, artwork, and i2c
2022-01-08 fixed some variable names and change name of i2c processor function
    [main.cpp]
2022-01-12 Fixed Errors and Logic, Also added libs to project file
    [OTS_Button.cpp, OTS_Button.h, OTS_Simon.cpp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]
2022-01-13 Fixed PROGMEM, missing `;`, constructors, and dsp
    [OTS_Button.cpp, OTS_Button.h, OTS_Simon.cpp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]
2022-01-13 added mod sets to i2c cmd processor
2022-01-14 Turned off debug, fixed copy
    [OTS_Button.cpp, OTS_Simon.cpp, OTS_Wires.cpp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]
2022-01-14 swaped to return vs clear
    [OTS_Button.cpp]
2022-01-16 fixed issus where seed clear would not clear userfaceing outputs
    [OTS_Button.cpp, main.cpp]
2022-01-17 moved screen drawing off the IPC loop to prevent hangups
    [OTS_Button.cpp, OTS_Button.h, main.cpp]
2022-01-18 Increased debounce time, and lockouts to prevent overcharging
    [OTS_Button.cpp, OTS_Button.h, main.cpp]
2022-01-18 I2C log level decreased, moved some stuff to selects, Added Audio Tick
2022-01-19 Fixed constant M2C interupt upon win
    [main.cpp]
2022-01-20 Added More RP2040 Specific Code and fixed timer check
    [OTS_Button.cpp, OTS_Button.h, main.cpp]
2022-01-22 Fixed Timer Issues
2022-01-22 Fixed RP2040 Addressing Issue
    [main.cpp]
2022-03-02 Added Calculation Dockuments
    [MKTNE OrderDock.xlsx, Resistor Values.xlsx]
2022-03-02 Updated to reflect PCB Design
2022-03-22 added 3d files for std config
    [Locking Pawl.3mf, Spring Cover.3mf]
2022-03-22 Added Phisical Details
    [OTS_Simon Back Cover.3mf, OTS_Simon Buttons.3mf, OTS_Simon Top Case.3mf]
2022-03-22 Added Physical Details
    [MKTNE_RPI_Shield 3d Files.f3d, MKTNE_RPI_Shield Top Cover.3mf]
2022-03-25 Updated Simon Test and phisicals
    [OTS_Simon Buttons.3mf, OTS_Simon Top Case.3mf]
2022-03-26 Updated Button Graphics
2022-03-26 Updated/Added Button Physical
    [OTS_Button Bottom Cover.3mf, OTS_Button Buttton Chasis.3mf, OTS_Button Switch to button chassis .3mf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]
2022-03-26 Updated Physical
    [MKTNE_RPI_Shield Top Cover.3mf]
2022-06-19 Its been a while
    [ArtBlank Filler.3mf, Frame v26.3mf, Resistor Values.xlsx]
2022-06-28 Updated test code to match PCB
2022-07-15 Finish Side Control Device Code
